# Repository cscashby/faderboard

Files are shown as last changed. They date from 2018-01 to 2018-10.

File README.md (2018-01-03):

# Fader Board (AKA Fraken-Mixer)

Multi-channel DAW control designed for portable wireless musical theatre use

## Problem statement

Normally musical theatre shows involve a fairly high number of radio microphones and a decent sized band/orchestra.  Generally in order to avoid feedback and other issues, the sound engineer needs to closely monitor / mix and quickly change faders during each scene to minimise the number of mics 'live' at any one time, and adjust for differences in the actors' voices and song dynamics.

In a traditional proscenium theatre this is fairly easy - a space is reserved at the back for the mix position, and the mixer and processing equipment (as well as the source for any SFX) is at the rear of the hall.

Enter promenade, or immersive, musical theatre - where the cast and audience are often in the same space, and the audience move through a number of rooms as the cast and the action takes them.

This is a very new genre of musical theatre, and hasn't really been done on a professional scale before - at least to my knowledge - and so when I was asked to do [Parade in Hemel Hempstead's Frogmore Paper Mill by Vivo D'Arte](http://www.vivodarte.co.uk/news.htm) - which required 20 radio microphones, a 7 piece orchestra, all in 5 different spaces, I apprehensively grasped at the challenge.

My approach at the time was to use a [Behringer Xtouch](https://www.musictri.be/Categories/Behringer/Computer-Audio/Desktop-Controllers/X-TOUCH/p/P0B1X) control surface, with a battery power unit and WiFi access client.  The result was good<sup>[1](#myfootnote1)</sup>, but it was a challenge because I only had 8 faders to use, couldn't change the 'page' or 'scene' myself, and couldn't trigger SFX or change speaker routing; I had a very capable team working with me who could do all of the above, so I managed, but it also was a very heavy box of tricks.

Another issue which arose over time was that the WiFi control was patchy - as the Xtouch isn't designed to be used with a spotty network connection, and being WiFi across a large space, the access client needed to disconnect and reconnect between multiple access points, disconnections were difficult - the Xtouch actually drops all the faders to -∞ so if you happen to touch them as it reconnects the channel dies unexpectedly. Not great.

So, what is required is a custom-built control surface which can control a number of channels of a mixing desk, without the constraints of a direct control solution like the Xtouch, and without the inherent problems with WiFi.

## Initial thoughts / concepts

### Scribble

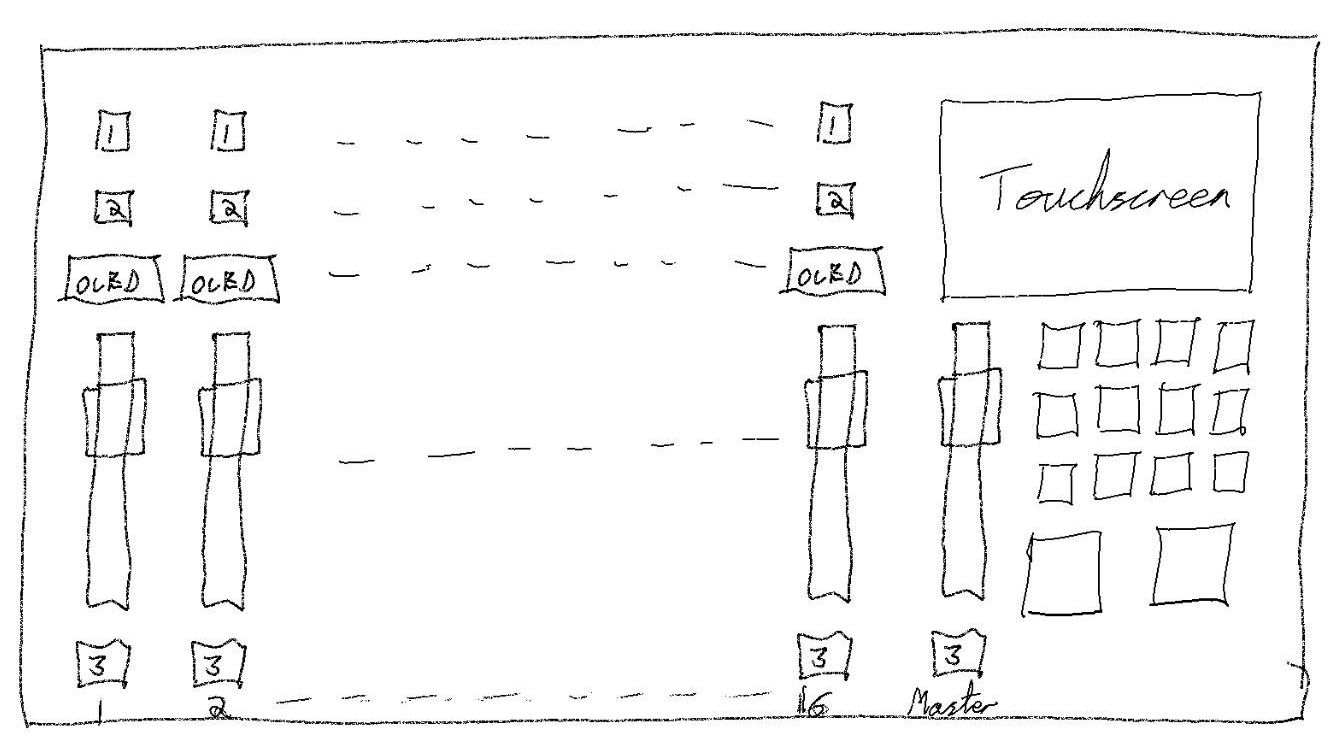
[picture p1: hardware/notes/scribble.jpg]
Scribbled picture of faderboard


Not very tidy, but hopefully this helps illustrate what's supposed to be happening.

### Tech decision

I went for an Arduino base for this project as I need embedded reliability and performance, without the overheads and inherent risks of using a SoC like the Raspberry Pi.  Given the complexity and number of I/O connections needed, I am basing the solution on an AT Mega 2560 - I got hold of [this dev board](http://amzn.to/2lO5UGc), but will probably design my own board from scratch for compactness

### Wireless comms

I need a long-range, full duplex transmit/receive solution for reasonably small payloads with a limited amount of overhead / latency.  I came across [LoRa](https://www.lora-alliance.org/) which seems to fit the bill, and I bought a couple of [dev boards for the RA-02 chip](http://amzn.to/2ELpx9M) which uses 433 MHz (or a couple of other free to use frequenceis).  I haven't completed testing yet but it seems to work well for my purposes.  What's more as it's designed for IoT, multiple receivers can be used to widen the transmit range if needed.

### Faders

Key to the solution is going to be the quality of fader units available, and they have to be motorised so they can be preset to values, and so that the sound #2s can also control if required.

Rather than evaluate a whole bunch of faders, I decided to buy [replacement faders for the Xtouch unit](https://www.gear4music.com/PA-DJ-and-Lighting/Behringer-X-Touch-Motor-Fader-MF100T-Set-of-5/1WME) instead - they are not that expensive, and I know them to be good.  They are 10 kΩ linear slide pots with a fast, accurate motor, and a touch sensitivity (capacitive touch) pin.

Touch sensitivity isn't something I've previously thought about, but this is a great option as it means that I can minimise my payload sent over the wire to only those faders which are being touched - making the device hopefully far more responsive.

### Scribble strips

Every good sound engineer deserves scribble strips (or something!) - they are invaluable for Musical Theatre - as each scene has different DCA assignments running, you can very quickly forget where you are as an operator.

I wanted multiple colours - as colour is a great way to distinguish between each channel.

I came across [these little OLED displays](https://thepihut.com/products/adafruit-monochrome-0-96-128x64-oled-graphic-display) which seem perfect as they're small, bright and easy to control via SPI.  I haven't yet received them so I'll update here as to how suitable they are.

Controlling lots of them isn't directly supported by their libraries so I'll need to do some custom coding to modify them for multiple units - multiplexing them through multiple CS pins.

### Everything else

I decided to duplicate the work I did in another project - '[pi-showcontrol'](github.com/cscashby/pi-showcontrol) and have a small TFT screen and programmable buttons in a 'master section' in the box - that way I can use SFX and have some feedback, possibly even plain text sent back to me by the Sound #2s which will hopefully be very useful.

### Power supply

This is probably the thing I've thought the least about.  I have a very reliable, high power battery which will give me any DC voltage I like and sensibly monitor time remaining, so I may stick with that for now; so a 5.5mm/2.5mm DC power jack may be all I need - probably 12v to minimise voltage regulator heating and run the whole thing at 5v.  However, if I feel brave later on I may well implement a battery control / charge unit.

### Physical manufacture

In my mind at present, I think the best approach is going to be to create a number of different PCBs:

1. Faders - in groups of 8 (so two identical boards).
2. Master control section - the TFT (although this may just be a module bolted to the case), buttons and big 'go' buttons).
3. Control board - the Arduino, radio chips and logic required to get the thing running.
4. Power supply - not sure what this will entail yet - watch this space.

I'd like to keep the unit as light as possible, but it will need sensible shielding (likely with pass-through capacitors for the 433 MHz antennae) - so I will be building the case out of sheet aluminium, probably cut using a CNC mill, or laser cut by a third party fabrication shop.  All of the controls will be mounted on the top panel, the control / power boards likely on the bottom panel, and the rear will be used for wired connections for charging, firmware upgrades and diagnostics.

On the sides of the box (which will likely need to be thicker / better reinforced) I will have holes for the straps which I will wear to use the unit whilst walking around (in [ice cream tray style](http://www.promotional-images.co.uk/ProdImages/2f9f440d-2c25-4093-97b0-d831b5edaa2b/classic2-lg.jpg) without the ice creams)

### The other end

Again this is early stages of the thought process, but a LoRa chip (probably the development board itself) with an ethernet HAT, which delivers an OSC payload to the mixing desk or a mac running [qLab](http://www.figure53.com/qlab).  Some form of queuing will be required so that if I end up with more than one of the receivers, then a controller will be required to marshal, deduplicate and send on this queue.

## Footnotes

<a name="myfootnote1">1</a>: 'No sitting at the back for him – [cscashby] he too followed the audience around with his sound desk in an usherette’s tray, ensuring that every cast member was heard, no matter what part of the building they were in.' [from Musical Theatre Review](http://musicaltheatrereview.com/parade-frogmore-paper-mill-hemel-hempstead/)

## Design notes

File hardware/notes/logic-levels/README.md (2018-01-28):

# Logic level conversion

Unfortunately the MPR121 is a 3.3v device not a 5v device, so I have decided to replace this more functional device with two CAP1296 devices, which only support 6 channels but don't require complex level shifting technology.

In case I need the MPR121 - I have included a reference to the Adafruit level shifter library which appears to be a good I2C solution.

https://github.com/adafruit/4-Channel-Level-Shifter-PCB

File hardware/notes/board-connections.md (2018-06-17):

# Faderboard connector layout

## CURRENT v1.0 board

|  **Connector** | **Pin** | **Signal Name** | **Notes** |
|  ---: | :---: | :---: | --- |
|  FD-J1 | 1 | GND |  |
|  FD-J1 | 2 | VCC / VDD | +3.3v |
|  FD-J1 | 3 | VREF | Vref |
|  FD-J1 | 4 | VMOTOR | +9v |
|  FD-J1 | 5 | GND | |
|  FD-J1 | 6 | VMOTOR | +9v |
|  FD-J1 | 7 | FSDAa | Fader touch I2C (1-4) |
|  FD-J1 | 8 | MCTLA | Motor Control |
|  FD-J1 | 9 | FSCLa | Fader touch I2C (1-4) |
|  FD-J1 | 10 | MCTLB | Motor Control |
|  FD-J1 | 11 | FI̅N̅T̅a | Fader touch interrupt (1-4) |
|  FD-J1 | 12 | BSEL | Board select (active HIGH) |
|  FD-J1 | 13 | FSDAb | Fader touch I2C (5-8) |
|  FD-J1 | 14 | FADER | Fader GND->Vref analogue |
|  FD-J1 | 15 | FSCLb | Fader touch I2C (5-8) |
|  FD-J1 | 16 | MA0 | Motor address LSB |
|  FD-J1 | 17 | FI̅N̅T̅b | Fader touch interrupt (5-8) |
|  FD-J1 | 18 | MA1 | Motor address |
|  FD-J1 | 19 | MA2 | Motor address MSB |
|  FD-J1 | 20 | FA0 | Fader address LSB |
|  FD-J1 | 21 | FA1 | Fader address |
|  FD-J1 | 22 | FA2 | Fader address MSB |
|  FD-J1 | 23 | GND | |
|  FD-J1 | 24 | DA0 | Display address LSB |
|  FD-J1 | 25 | DA1 | Display address |
|  FD-J1 | 26 | DA2 | Display address MSB |
|  FD-J1 | 27 | GND | |
|  FD-J1 | 28 | DSDA | Display SDA |
|  FD-J1 | 29 | DDC̅ | Display D/C |
|  FD-J1 | 30 | DSCL | Display SCL |
|  FD-J1 | 31 | DC̅S̅ | Display CS |
|  FD-J1 | 32 | DR̅S̅T̅ | Display Reset |

#### Connector layout

|  **Name** | **Pin** | **Pin** | **Name** |
|  ---: | :---: | :---: | --- |
|  GND | 1 | 2 | VCC / VDD |
|  VREF | 3 | 4 | VMOTOR |
|  GND | 5 | 6 | VMOTOR |
|  FSDAa | 7 | 8 | MCTLA |
|  FSCLa | 9 | 10 | MCTLB |
|  FI̅N̅T̅a | 11 | 12 | BSEL |
|  FSDAb | 13 | 14 | FADER |
|  FSCLb | 15 | 16 | MA0 |
|  FI̅N̅T̅b | 17 | 18 | MA1 |
|  MA2 | 19 | 20 | FA0 |
|  FA1 | 21 | 22 | FA2 |
|  GND | 23 | 24 | DA0 |
|  DA1 | 25 | 26 | DA2 |
|  GND | 27 | 28 | DSDA |
|  DDC̅ | 29 | 30 | DSCL |
|  DC̅S̅ | 31 | 32 | DR̅S̅T̅ |

## OLD VERSION v0.1

### 8-fader and OLED board

#### By pin

|  **Connector** | **Pin** | **Signal Name** | **Notes** |
|  ---: | :---: | :---: | --- |
|  FD-J1 | 1 | GND |  |
|  FD-J1 | 2 | VCC / VDD | +3.3v |
|  FD-J1 | 3 | VREF | Vref |
|  FD-J1 | 4 | GND |  |
|  FD-J1 | 5 | GND |  |
|  FD-J1 | 6 | VMOTOR | +12v TBC |
|  FD-J1 | 7 | FSDAa | I2C for first CAP1296 |
|  FD-J1 | 8 | MCTLA | Motor Control |
|  FD-J1 | 9 | FSCLa | I2C for first CAP1296 |
|  FD-J1 | 10 | MCTLB | Motor Control |
|  FD-J1 | 11 | GND |  |
|  FD-J1 | 12 | FIRQ | For touch (active Low) |
|  FD-J1 | 13 | FSDAb | I2C for first CAP1296 |
|  FD-J1 | 14 | FADER | Fader GND->Vref |
|  FD-J1 | 15 | FSCLb | I2C for first CAP1296 |
|  FD-J1 | 16 | MA0 | Motor address LSB |
|  FD-J1 | 17 | MA1 | Motor address |
|  FD-J1 | 18 | MA2 | Motor address MSB |
|  FD-J1 | 19 | MA3 | Motor enable for board (active High) |
|  FD-J1 | 20 | FA0 | Fader address LSB |
|  FD-J1 | 21 | FA1 | Fader address |
|  FD-J1 | 22 | FA2 | Fader address MSB |
|  FD-J1 | 23 | FA3 | Fader enable for board (active High) |
|  FD-J1 | 24 | DA0 | Display address LSB |
|  FD-J1 | 25 | DA1 | Display address |
|  FD-J1 | 26 | DA2 | Display address MSB |
|  FD-J1 | 27 | DA3 | Display enable for board (active High) |
|  FD-J1 | 28 | DRST | Display Reset |
|  FD-J1 | 29 | DDC | Display D/C |
|  FD-J1 | 30 | BSEL | Board select (MPR121 I2C addr GND = 0x5a, VCC = 0x5b) |
|  FD-J1 | 31 | GND |  |
|  FD-J1 | 32 | GND |  |

#### Connector layout

|  **Name** | **Pin** | **Pin** | **Name** |
|  ---: | :---: | :---: | --- |
|  GND | 1 | 2 | VCC / VDD |
|  VREF | 3 | 4 | GND |
|  GND | 5 | 6 | VMOTOR |
|  FSDAa | 7 | 8 | MCTLA |
|  FSCLa | 9 | 10 | MCTLB |
|  GND | 11 | 12 | FIRQ |
|  FSDAb | 13 | 14 | FADER |
|  FSCLb | 15 | 16 | MA0 |
|  MA1 | 17 | 18 | MA2 |
|  MA3 | 19 | 20 | FA0 |
|  FA1 | 21 | 22 | FA2 |
|  FA3 | 23 | 24 | DA0 |
|  DA1 | 25 | 26 | DA2 |
|  DA3 | 27 | 28 | DRST |
|  DDC | 29 | 30 | BSEL |
|  GND | 31 | 32 | GND |

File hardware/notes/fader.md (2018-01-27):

Fader appears to be an Alps RSA0N11M9A0J.

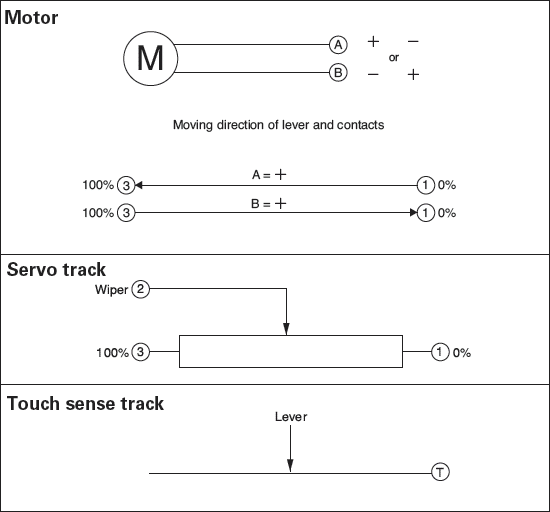
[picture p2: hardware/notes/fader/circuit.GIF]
Fader Circuit Fader circuit


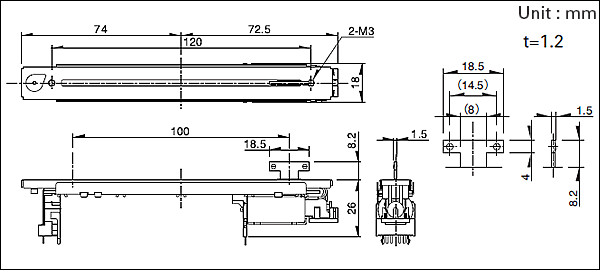
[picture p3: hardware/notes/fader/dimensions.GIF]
Fader Dimensions Fader dimensions


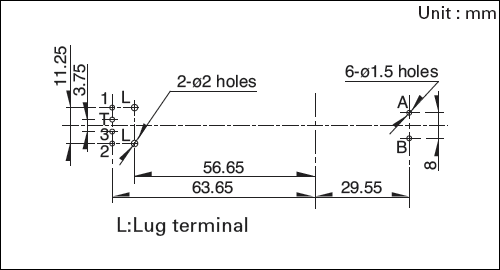
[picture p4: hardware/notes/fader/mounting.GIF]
Fader Mounting Fader mounting


Specs:

Number of resistor elements | Single-unit |
Direction of lever | Vertical |
Travel | 100mm |
Type | Motor N fader |
Lever type | 9-T (T-Bar) |
Length of lever | 8.2mm |
Total resistance | 10kΩ |
Resistance taper | 1B |
Terminal style | For PC board |
Touch sense track | With |
Operating temperature range | -10°C to +60°C |
Electrical performance | Total resistance tolerance | ±20%
Maximum operating voltage | 500V AC, 10V DC |
Rated voltage of motor | 10V DC |
Maximum current of motor | 800mA or less (at 10V DC) |
Rated power | 0.5W |
Insulation resistance | 100MΩ min. 250V DC |
Voltage proof | 250V AC for 1 minute |
Mechanical performance | Operating force | 0.8±0.5N |
Stopper strength | 100N |
Lever push-pull strength | 50N |
Lever wobble (Both side) | 1.312mm |
Lever deviation (One side) | 0.5mm max. |
Durability | Operating life | 30,000 cycles |
Minimum order unit (pcs.) | Japan | 80
Export | 160 |

http://www.alps.com/prod/info/E/HTML/Potentiometer/SlidePotentiometers/RSN1M/RSA0N11M9A0J.html

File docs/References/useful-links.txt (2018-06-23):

Mega2560 docs:

https://store.arduino.cc/arduino-mega-2560-rev3

Multiplexing SPI lines:

https://forum.arduino.cc/index.php?topic=461410.0

Arduino/LoRA:

https://github.com/sandeepmistry/arduino-LoRa#semtech-sx1276777879-wiring

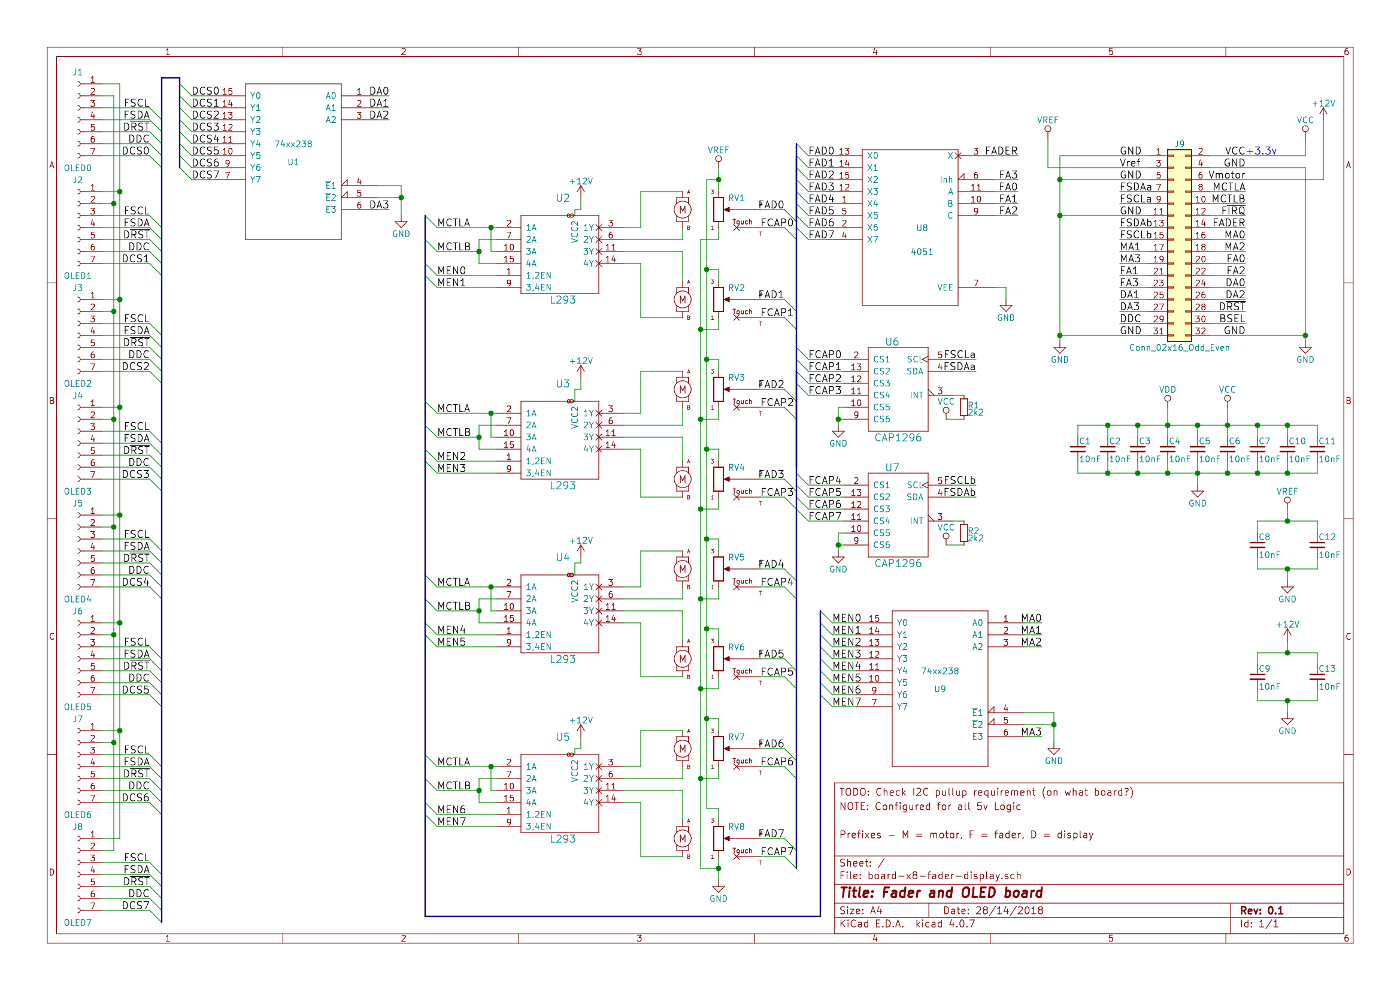
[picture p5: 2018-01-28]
hardware/board-x8-fader-display.v0.1.png

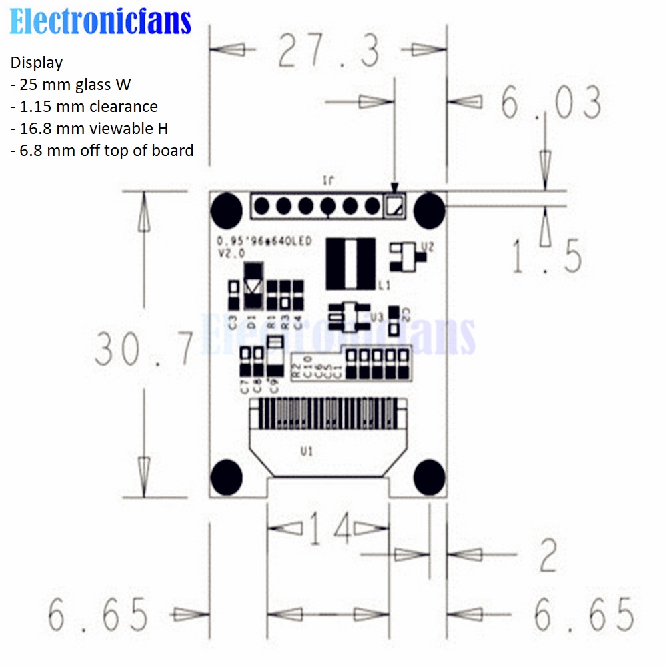
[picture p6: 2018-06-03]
docs/Datasheets/0-95-Inch-SPI-Full-Color-OLED-Display-DIY-Module-96x64-LCD-For-Arduino-SSD1306-Driver.jpg

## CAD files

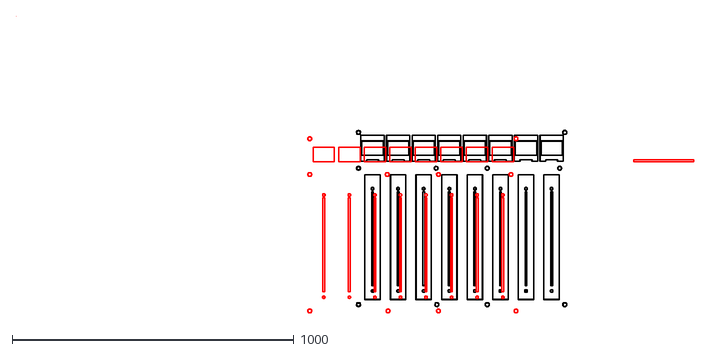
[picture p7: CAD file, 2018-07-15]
docs/Boards/Fader T-Slot Box.dxf
2401.2 x 1052.8

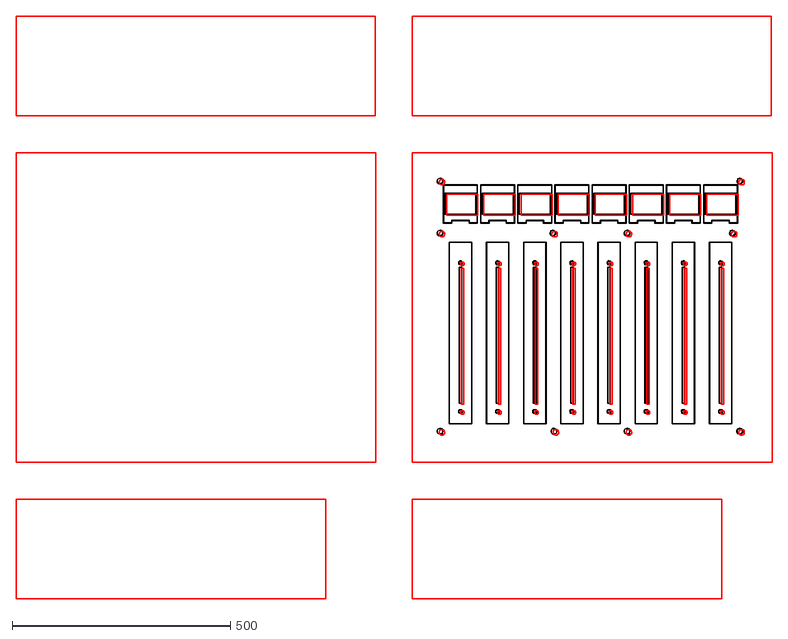
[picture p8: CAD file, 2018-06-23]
docs/Boards/Fader Lasercut.dxf
1730.4 x 1332.3

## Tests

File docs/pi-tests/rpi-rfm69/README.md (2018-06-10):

Pi setup notes

raspi-config #- enable SPI
pip install rpi-rfm69

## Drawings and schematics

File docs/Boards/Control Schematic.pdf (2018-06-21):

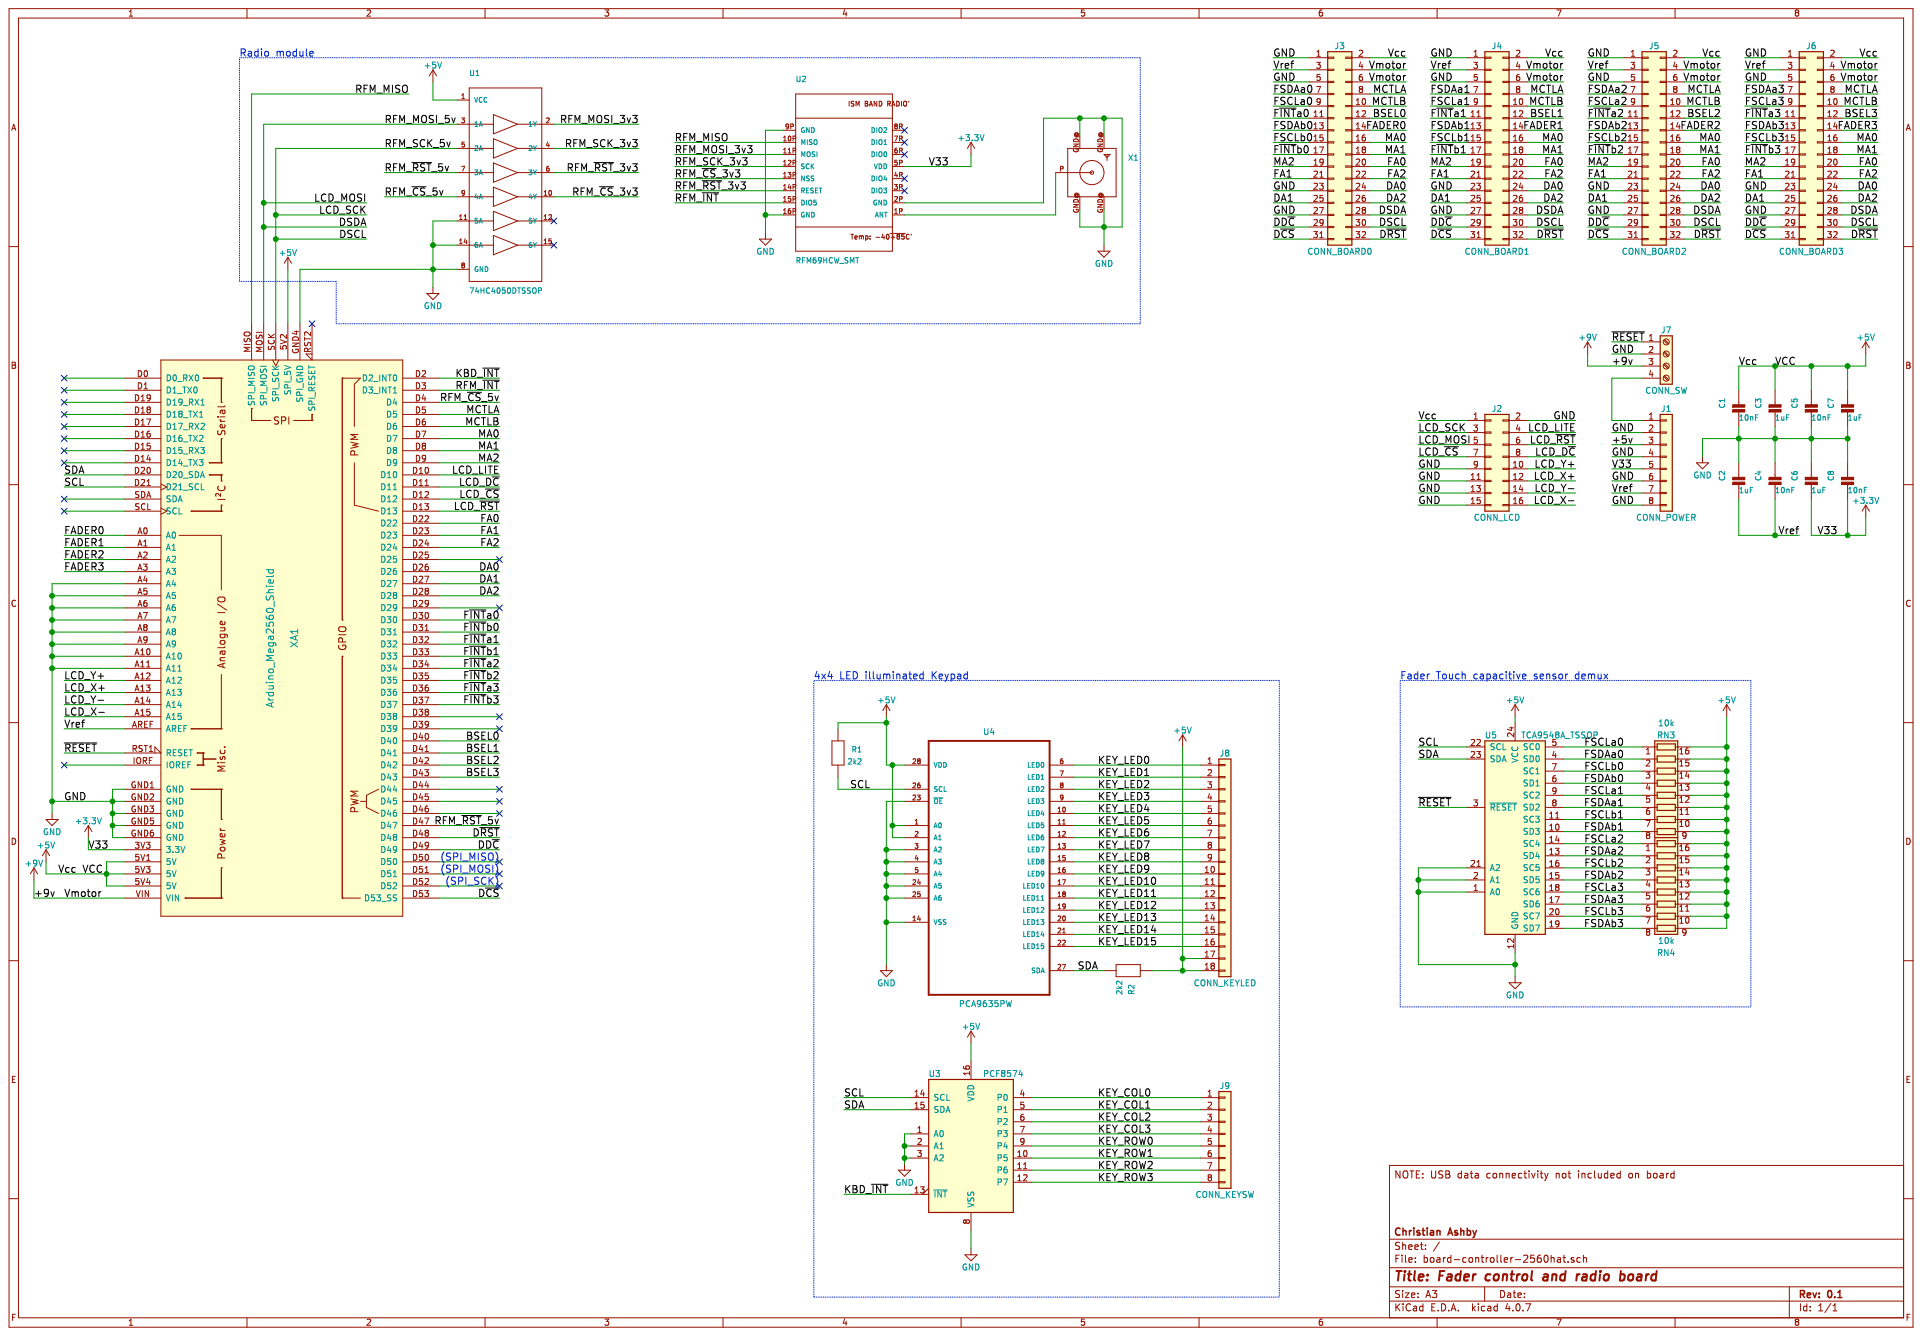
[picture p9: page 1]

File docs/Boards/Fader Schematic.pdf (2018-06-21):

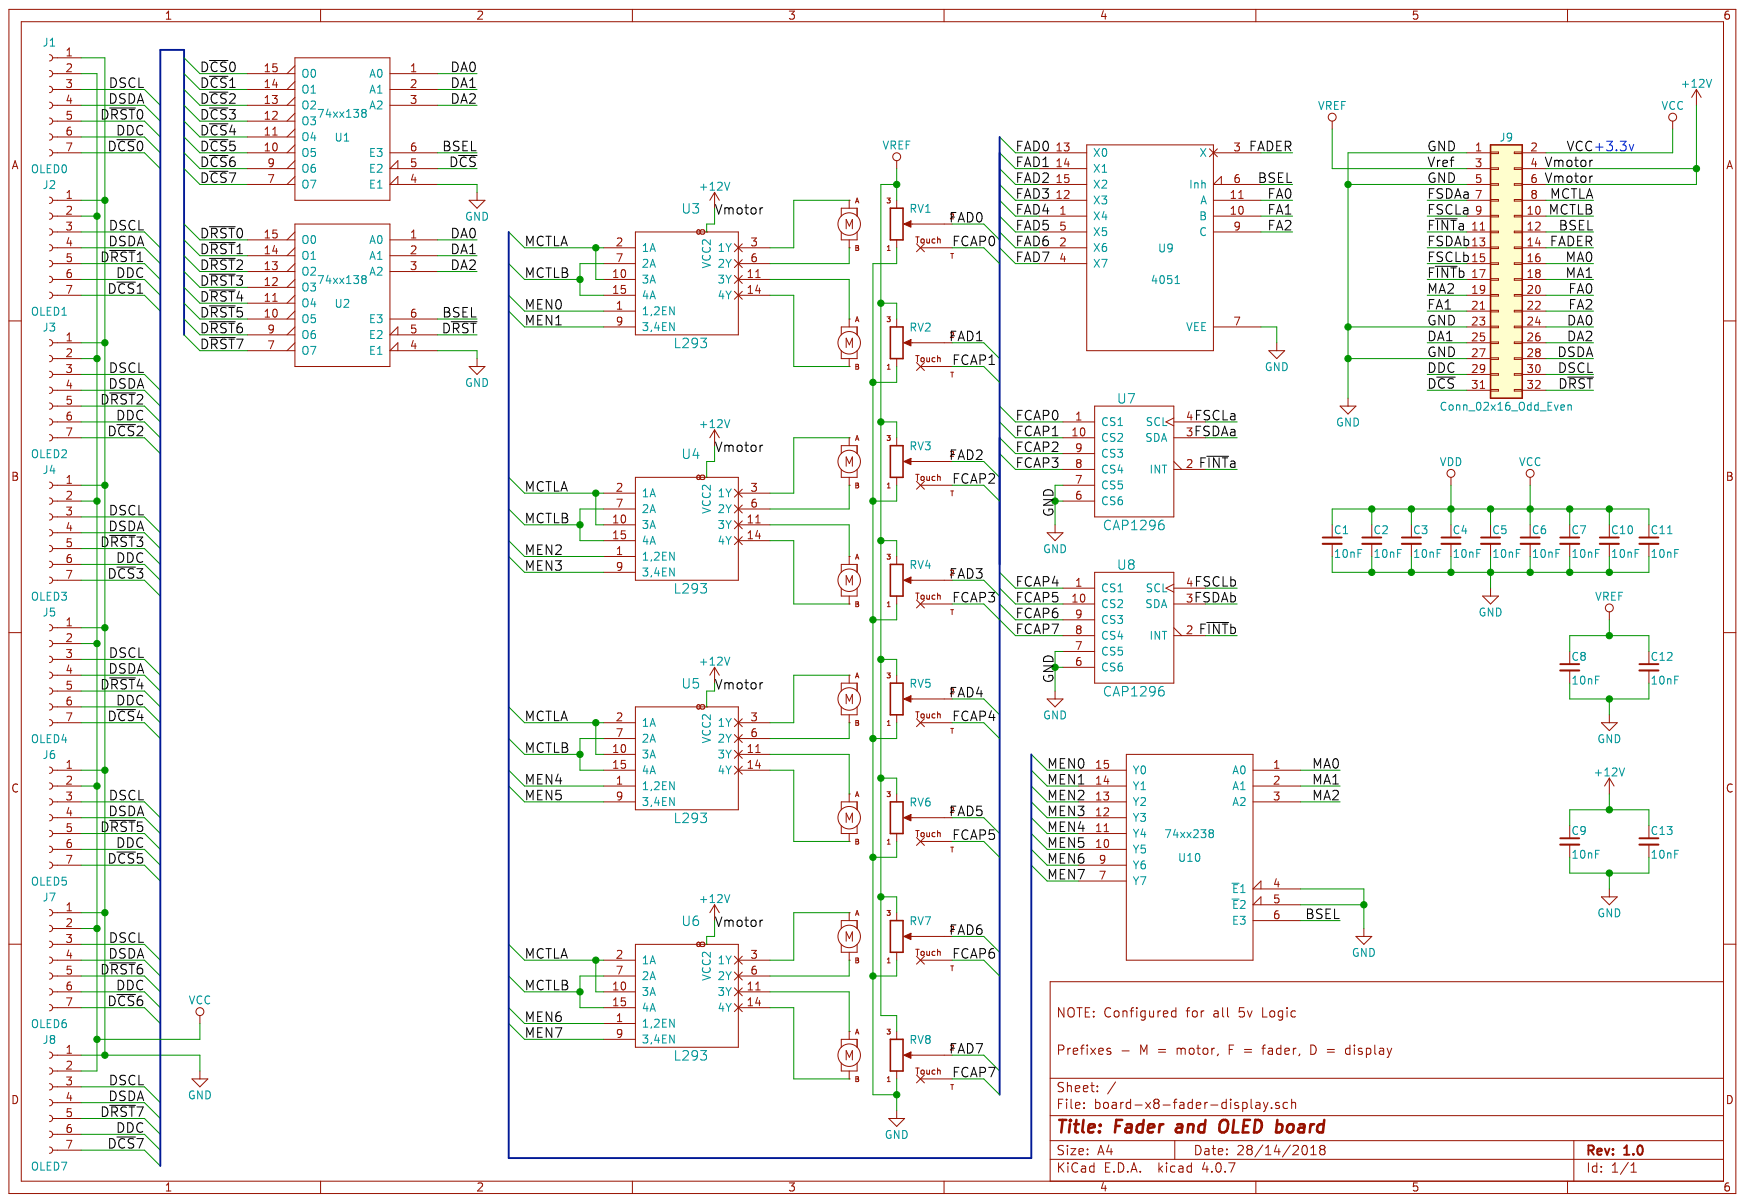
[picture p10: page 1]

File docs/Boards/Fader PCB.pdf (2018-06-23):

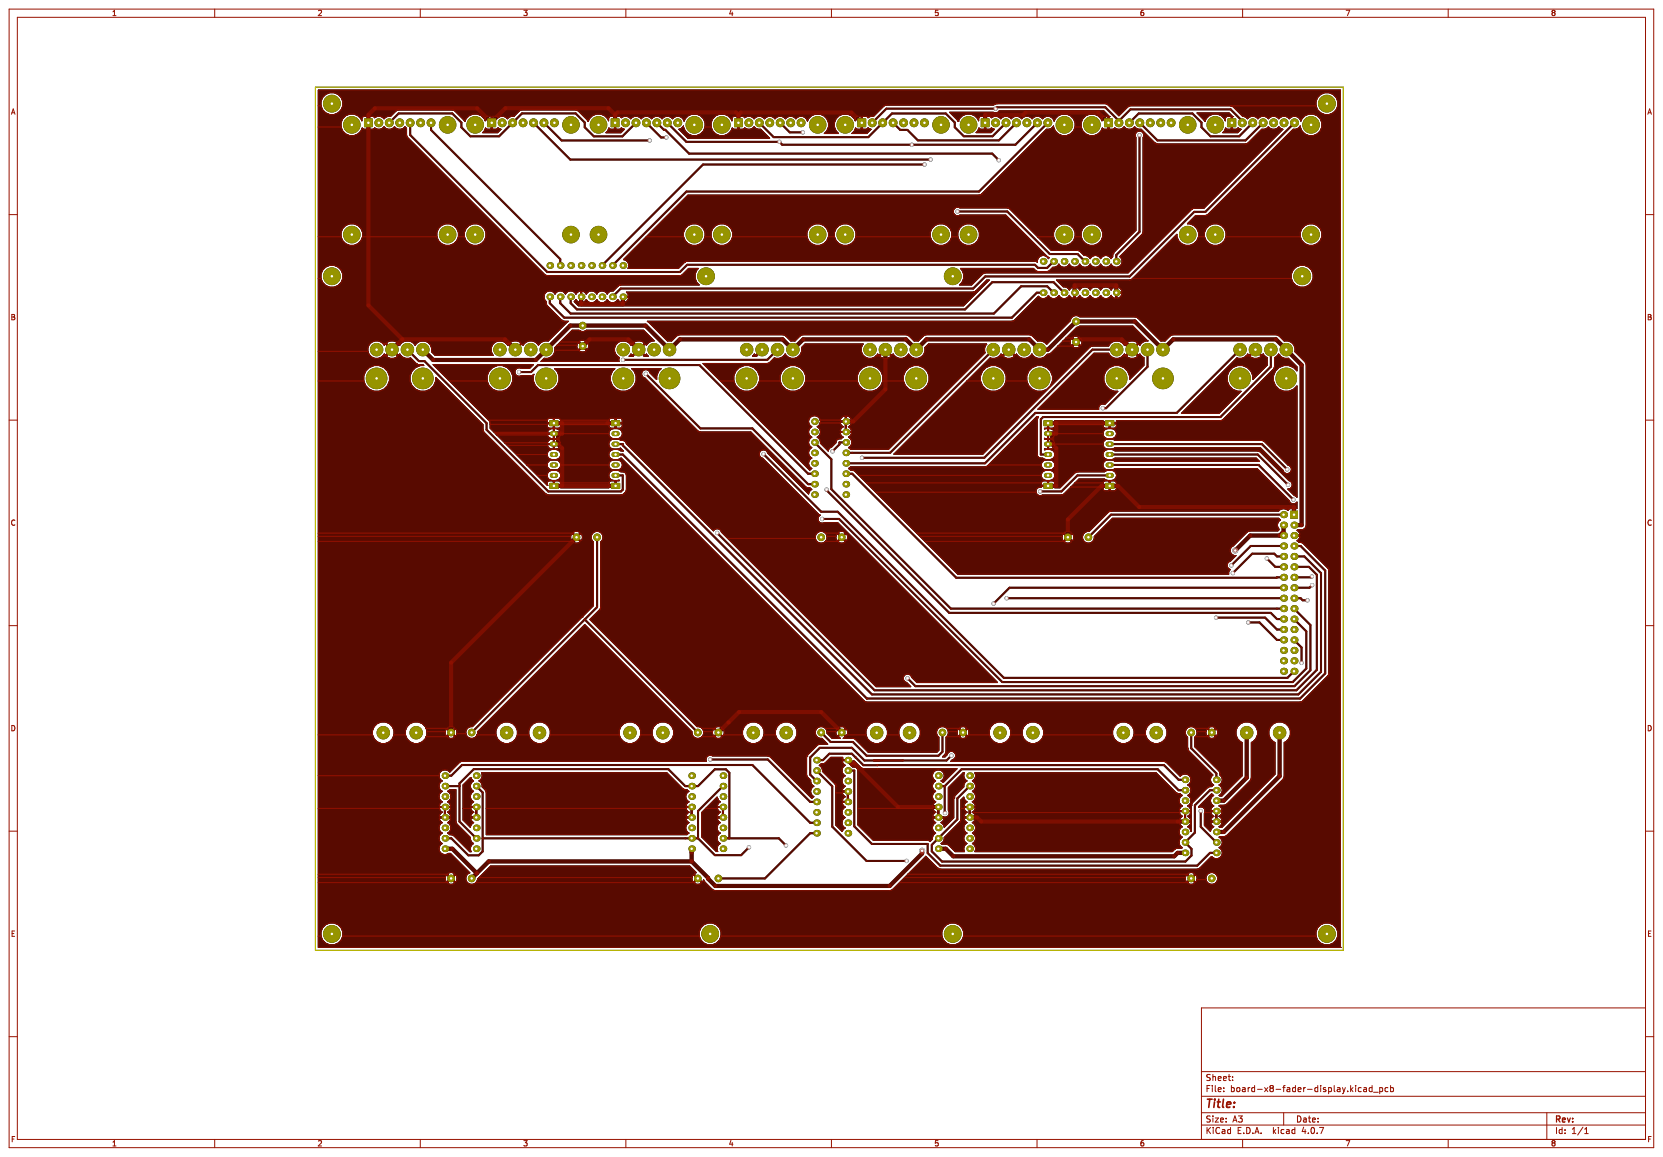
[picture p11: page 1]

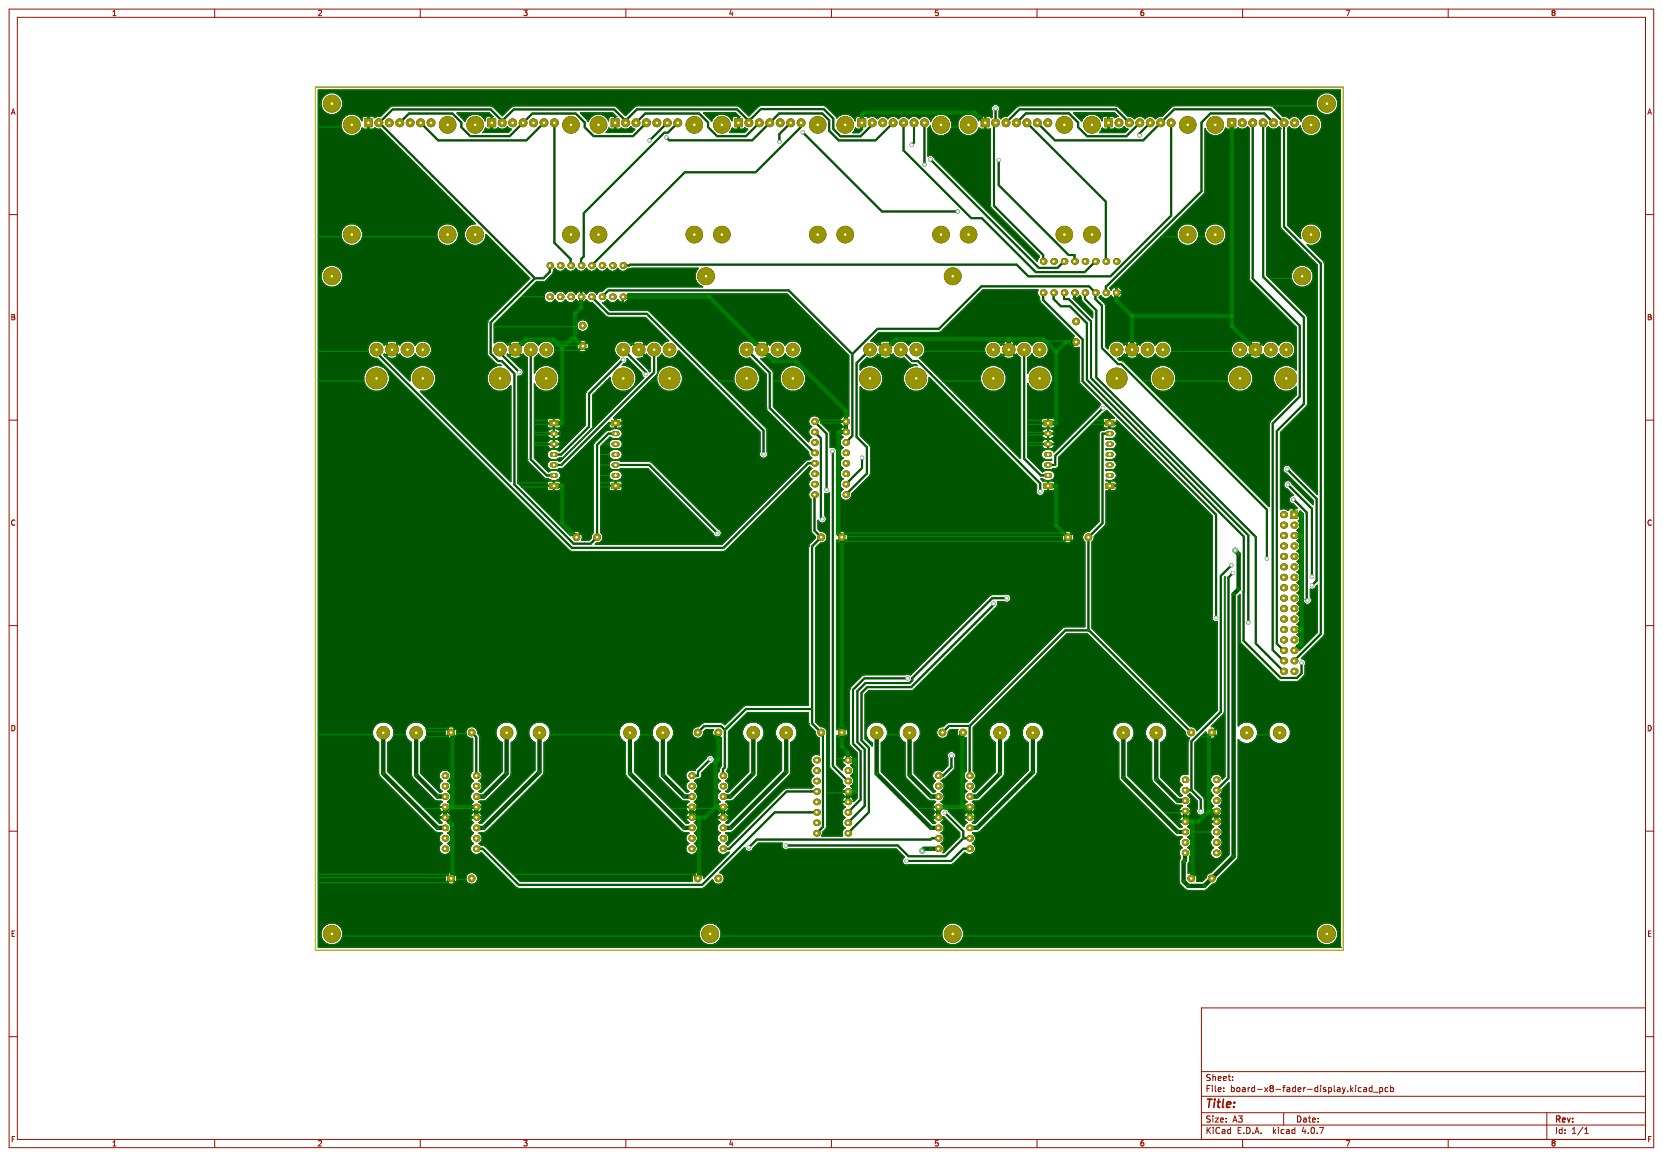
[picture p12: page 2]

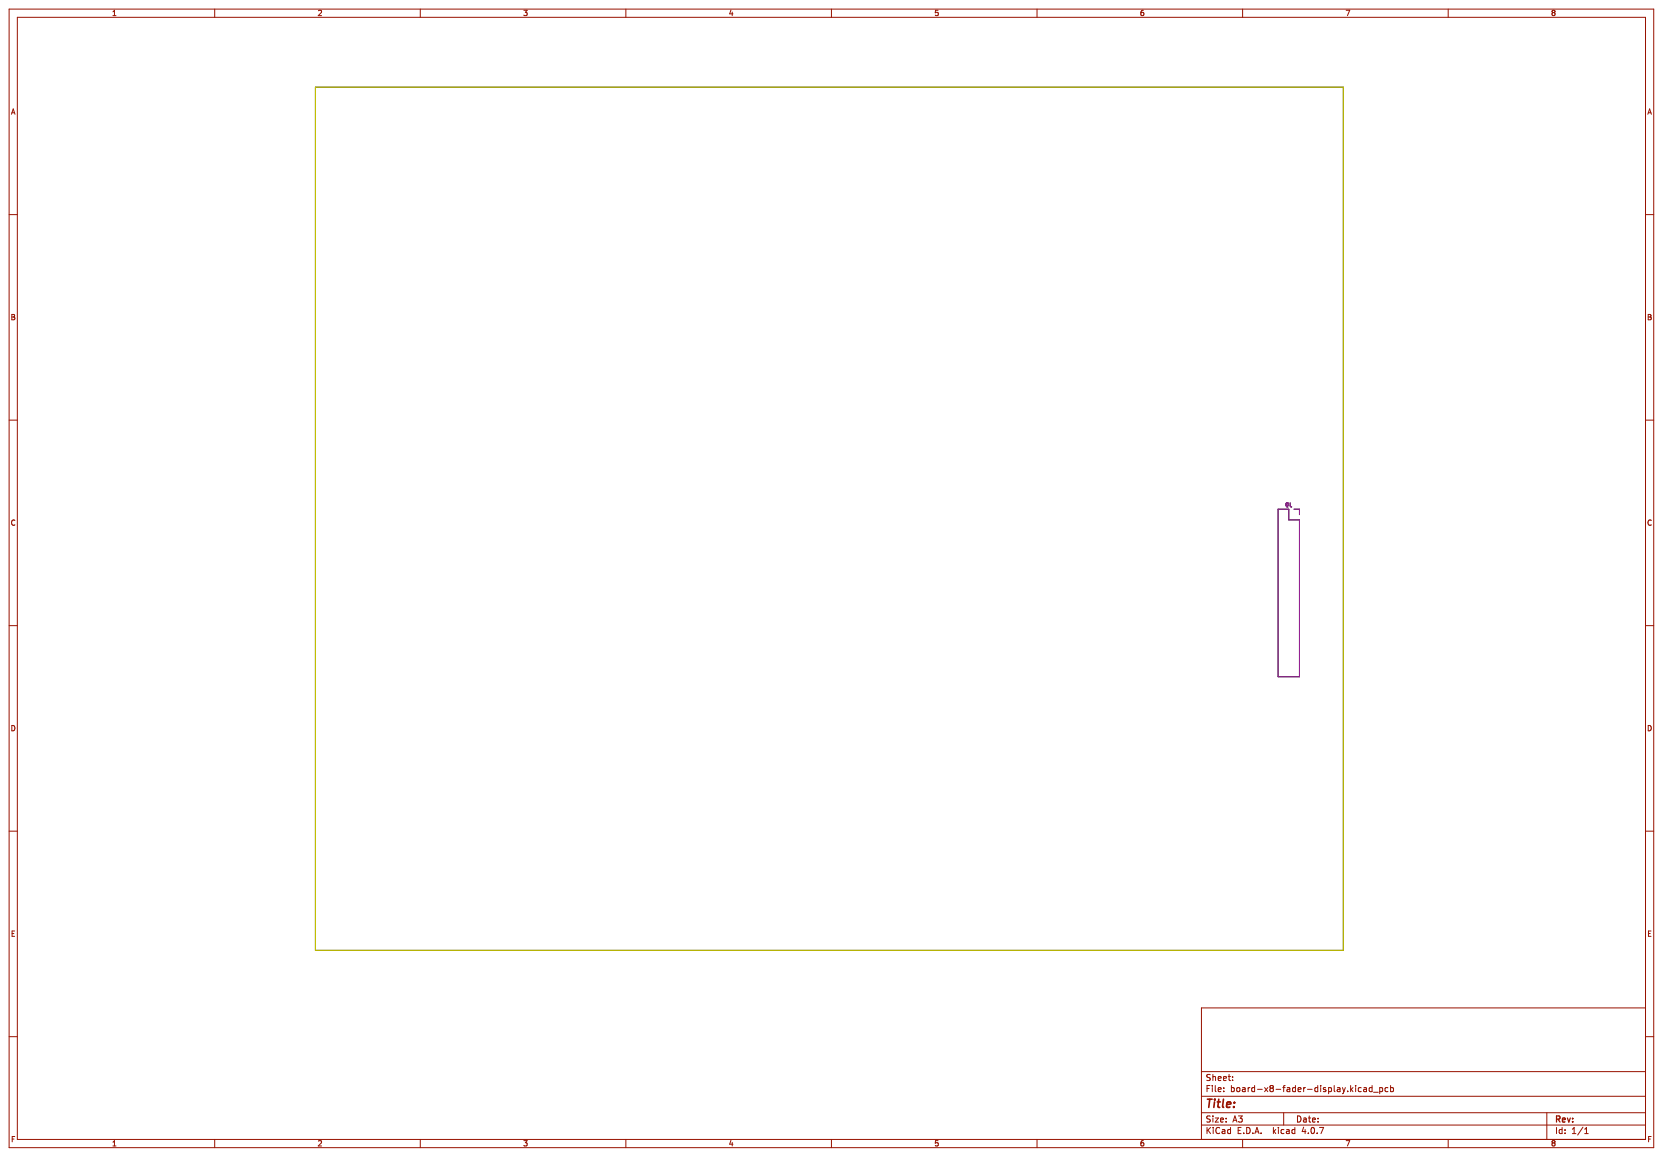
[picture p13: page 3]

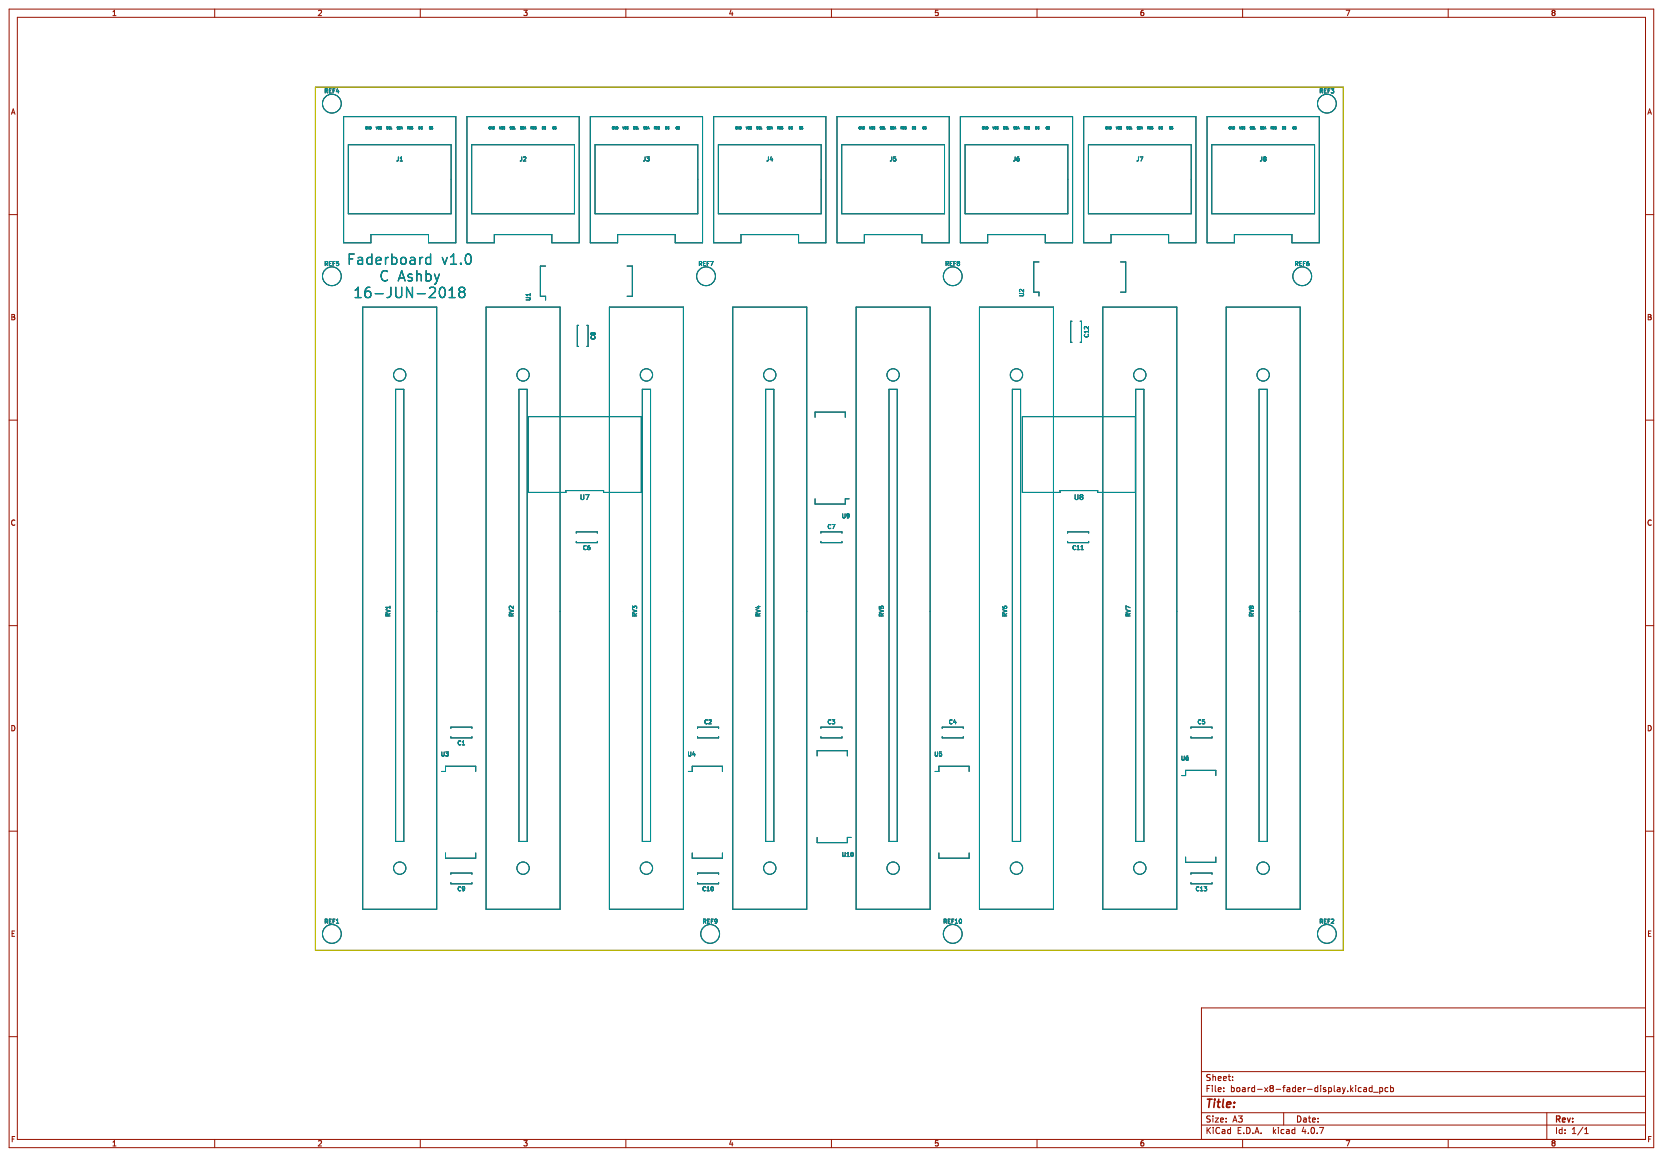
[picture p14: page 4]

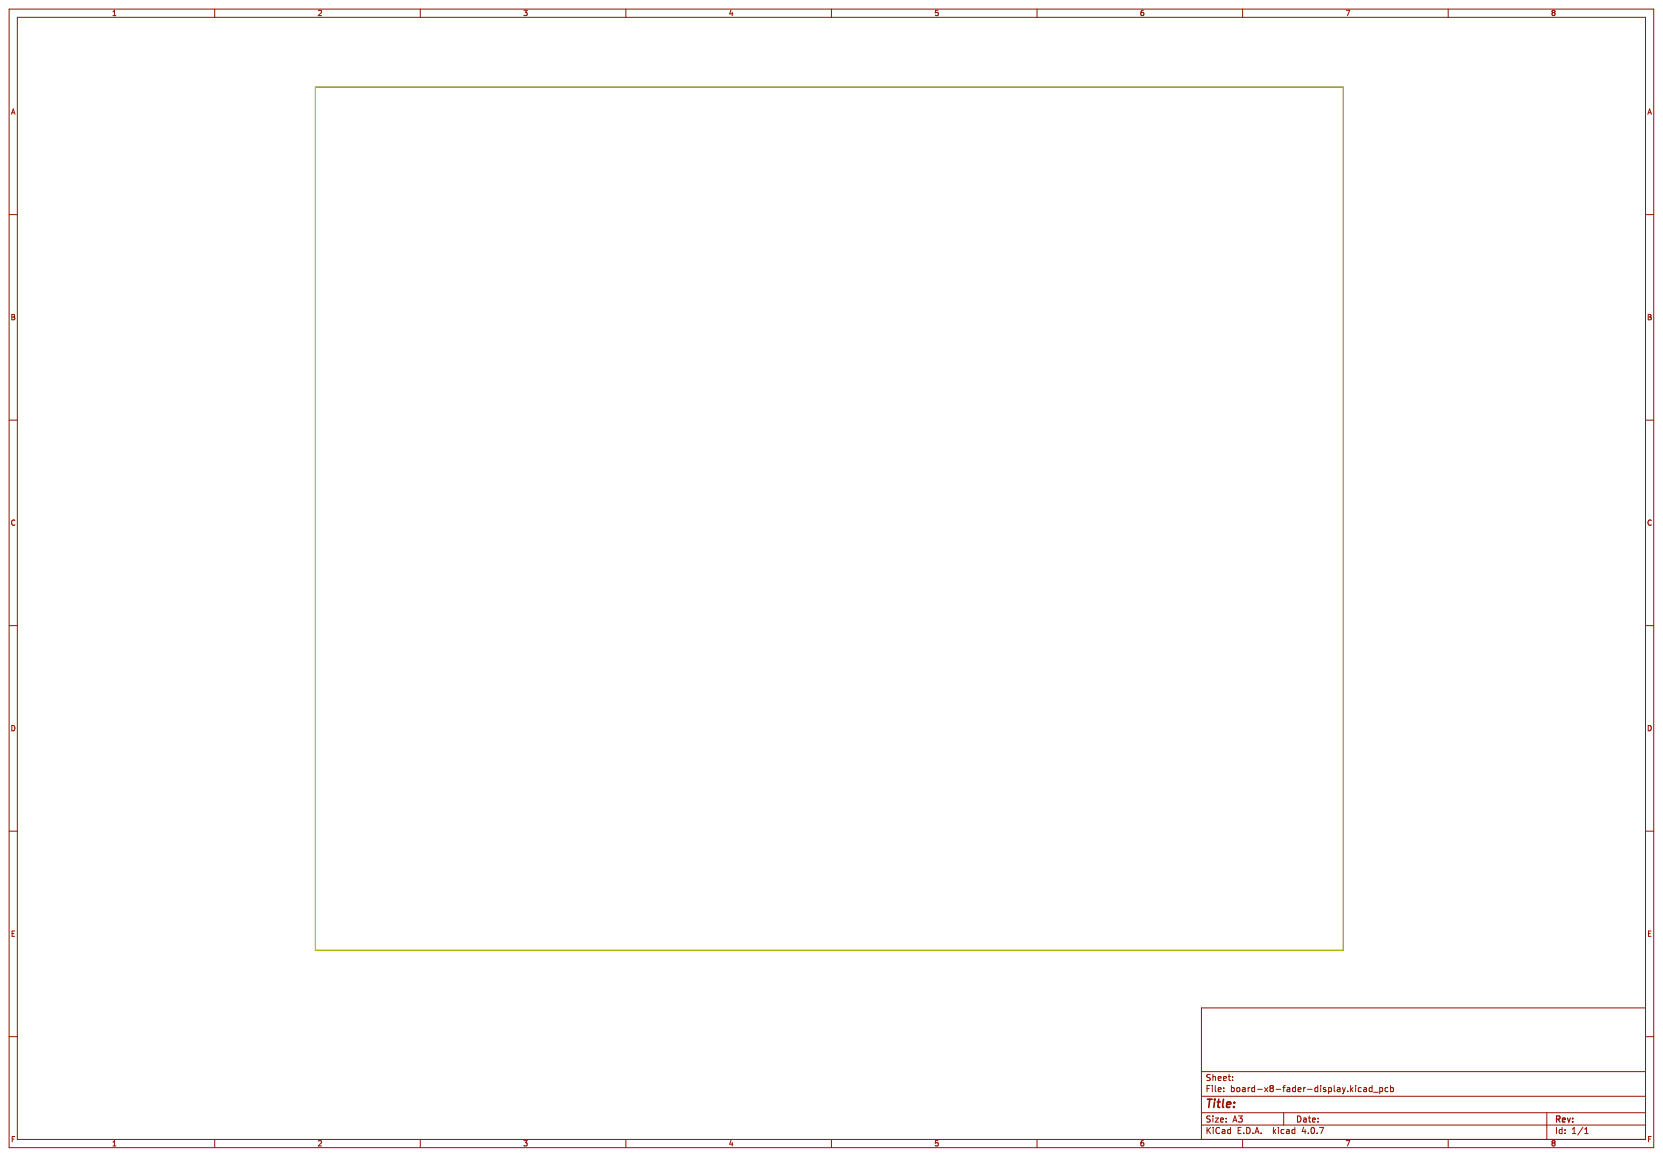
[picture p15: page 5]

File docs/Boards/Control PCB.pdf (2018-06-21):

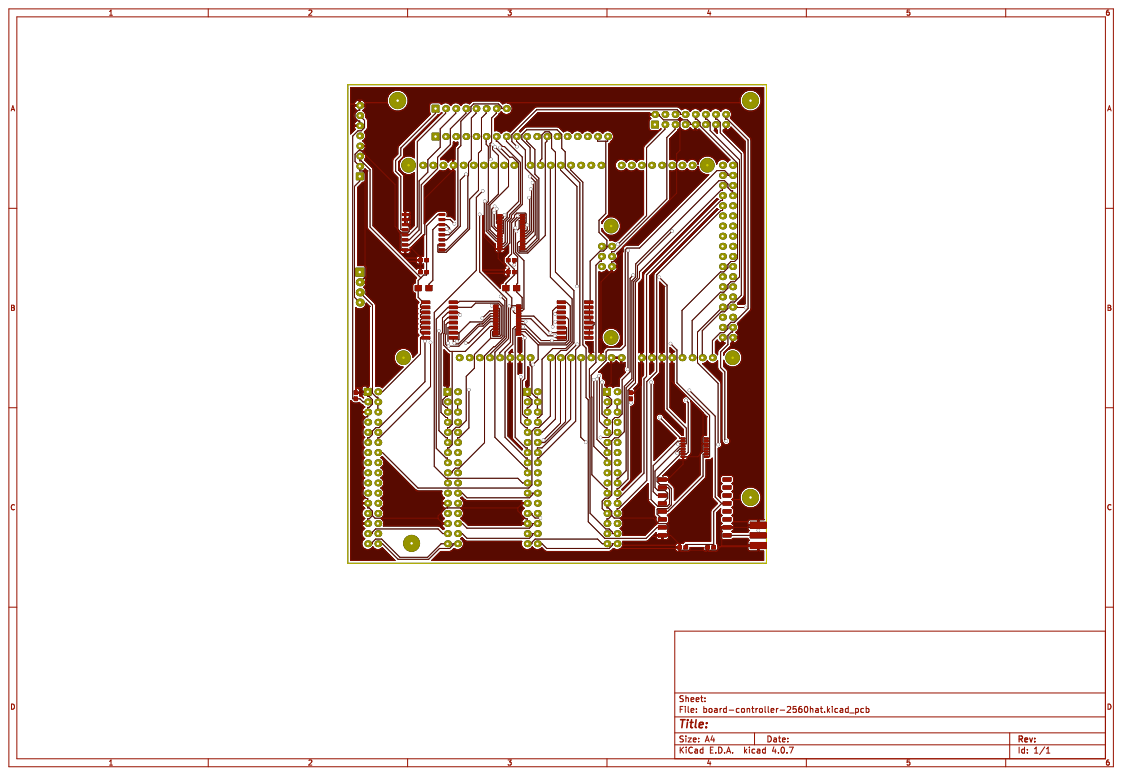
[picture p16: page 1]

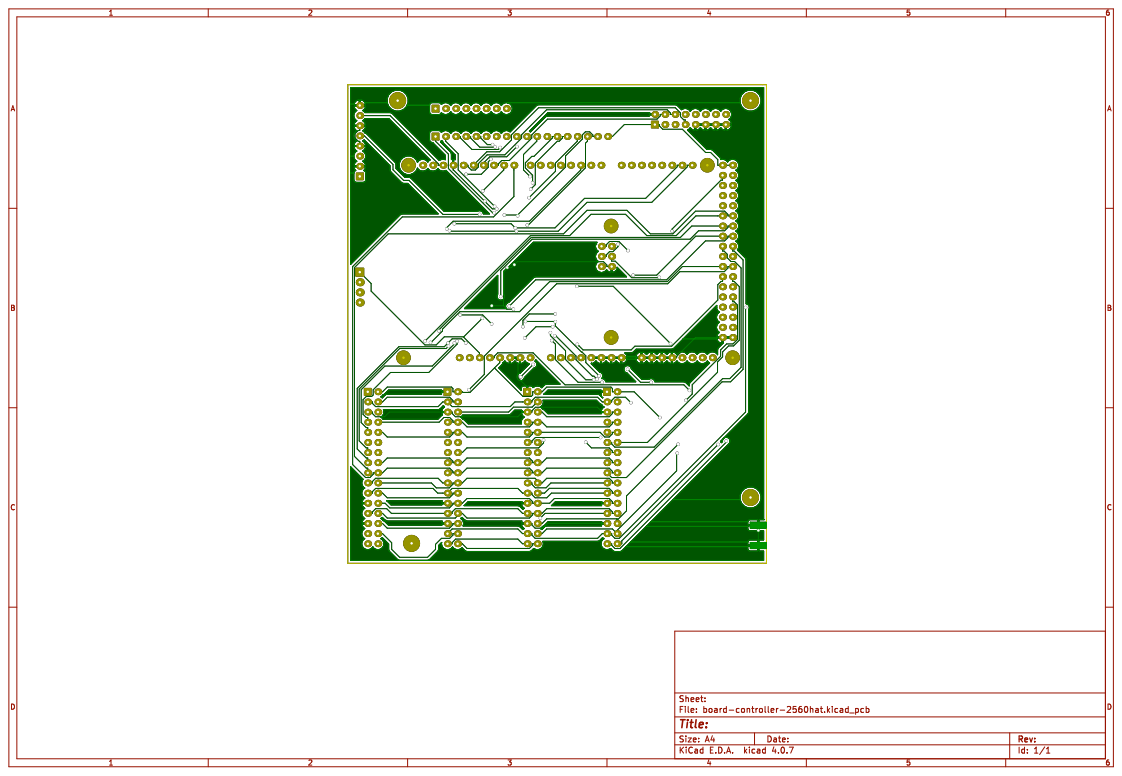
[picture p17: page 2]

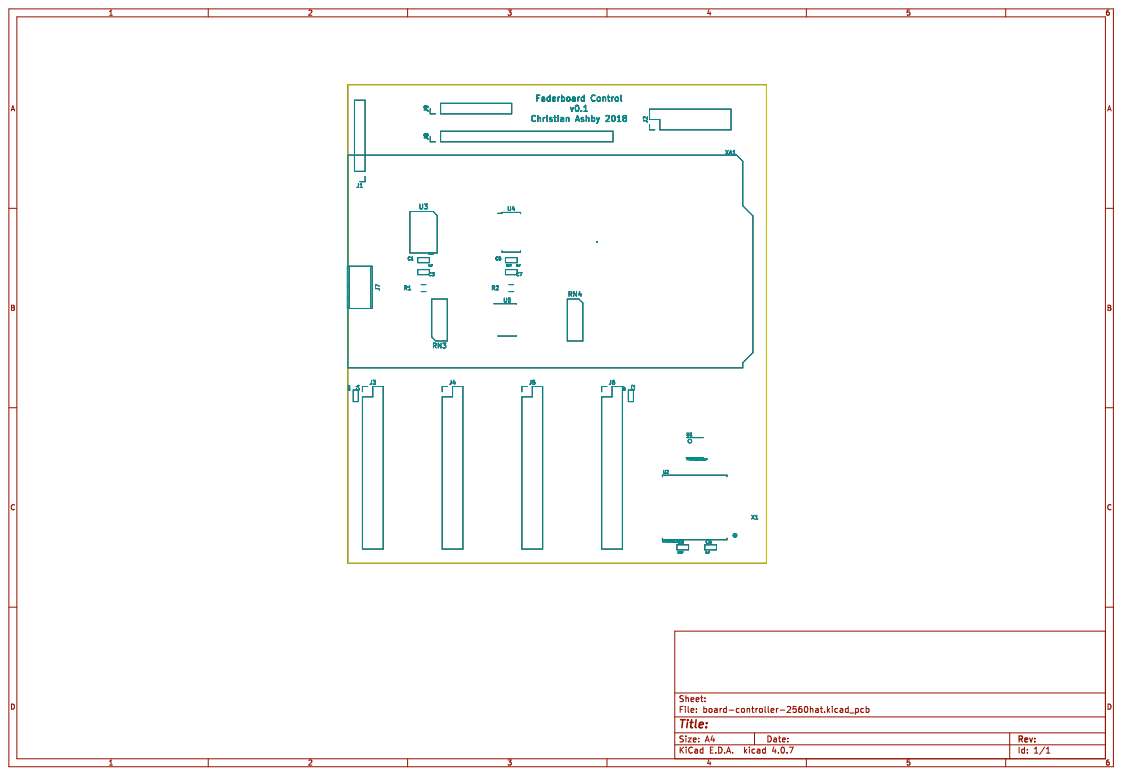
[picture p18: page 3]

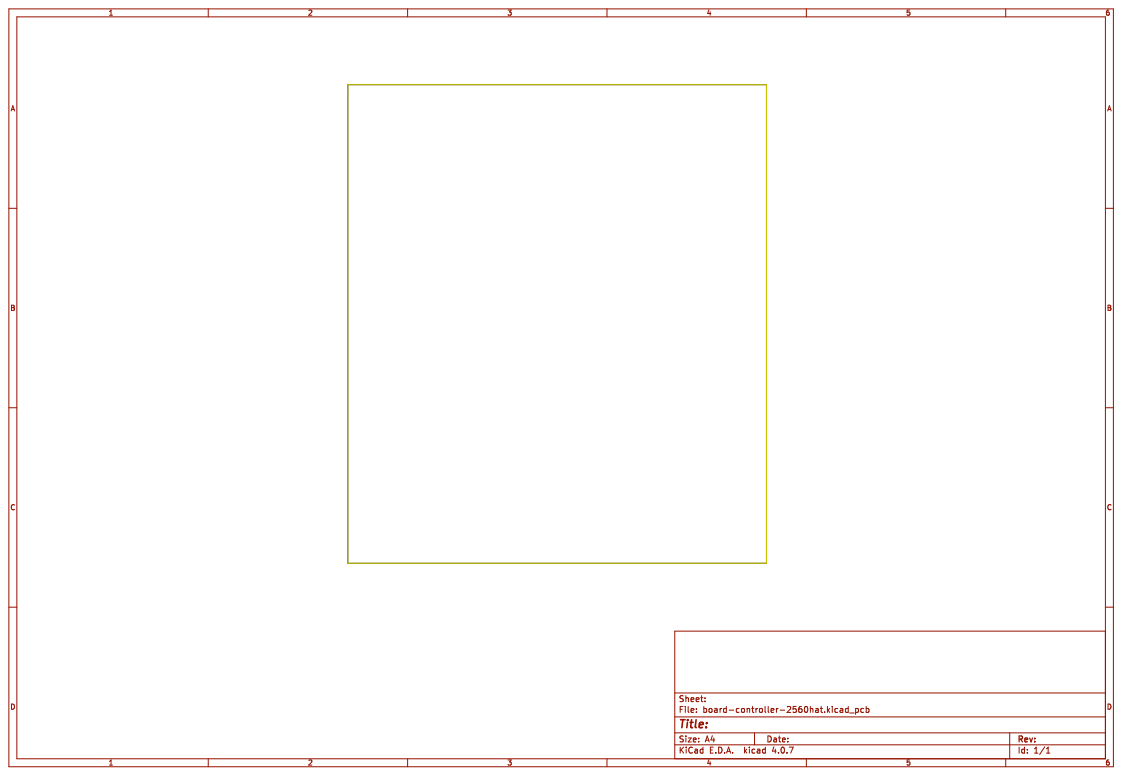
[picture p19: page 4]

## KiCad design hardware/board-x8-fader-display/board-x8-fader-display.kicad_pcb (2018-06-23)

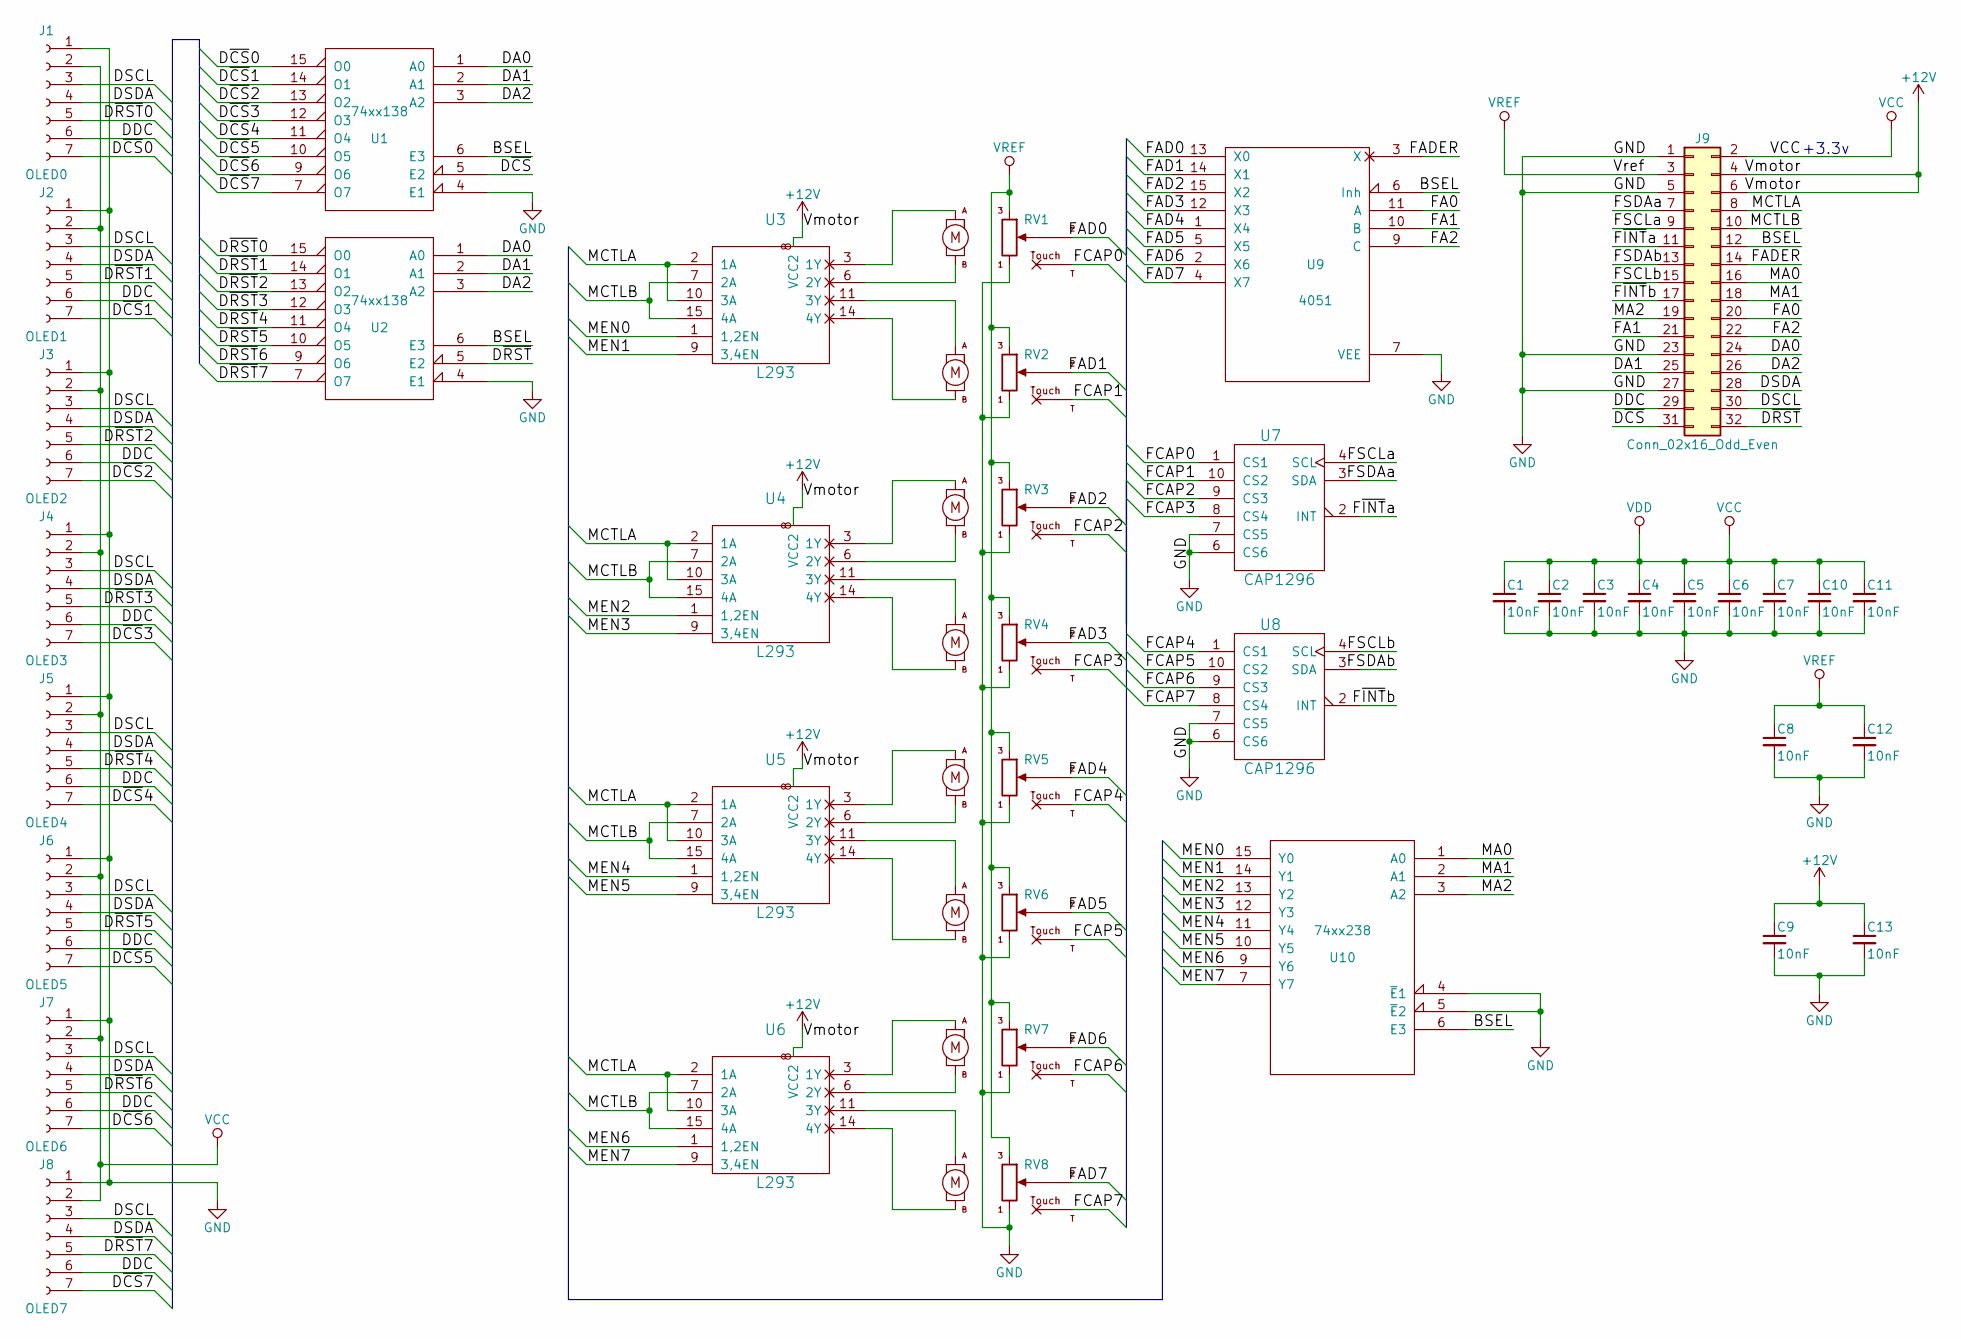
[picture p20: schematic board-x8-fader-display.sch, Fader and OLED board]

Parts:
C1, C2, C3, C4, C5, C6, C7, C8, C9, C10, C11, C12, C13: 10nF; C_Disc_D5.0mm_W2.5mm_P5.00mm
J1: OLED0; 0.95_SPI_SSD1306_Display
J2: OLED1; 0.95_SPI_SSD1306_Display
J3: OLED2; 0.95_SPI_SSD1306_Display
J4: OLED3; 0.95_SPI_SSD1306_Display
J5: OLED4; 0.95_SPI_SSD1306_Display
J6: OLED5; 0.95_SPI_SSD1306_Display
J7: OLED6; 0.95_SPI_SSD1306_Display
J8: OLED7; 0.95_SPI_SSD1306_Display
J9: Conn_02x16_Odd_Even; Pin_Header_Straight_2x16_Pitch2.54mm
RV1, RV2, RV3, RV4, RV5, RV6, RV7, RV8: RSA0N11M9A0J; AlpsFader_RSA0N11M9A0J
U1, U2: 74xx138; DIP-16_W7.62mm
U3, U4, U5, U6: L293; DIP-16_W7.62mm
U7, U8: CAP1296; DFN-10-1EP_3x3mm_Pitch0.5mm
U9: 4051; DIP-16_W7.62mm
U10: 74xx238; DIP-16_W7.62mm

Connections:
+12V: C9.1, C13.1, J9.4, J9.6, U3.8 (VCC2), U4.8 (VCC2), U5.8 (VCC2), U6.8 (VCC2)
/BSEL: J9.12, U1.6 (E3), U2.6 (E3), U9.6 (Inh), U10.6 (E3)
/DA0: J9.24, U1.1 (A0), U2.1 (A0)
/DA1: J9.25, U1.2 (A1), U2.2 (A1)
/DA2: J9.26, U1.3 (A2), U2.3 (A2)
/DDC: J1.6, J2.6, J3.6, J4.6, J5.6, J6.6, J7.6, J8.6, J9.29
/DSCL: J1.3, J2.3, J3.3, J4.3, J5.3, J6.3, J7.3, J8.3, J9.30
/DSDA: J1.4, J2.4, J3.4, J4.4, J5.4, J6.4, J7.4, J8.4, J9.28
/D~CS~: J9.31, U1.5 (E2)
/D~CS~0: J1.7, U1.15 (O0)
/D~CS~1: J2.7, U1.14 (O1)
/D~CS~2: J3.7, U1.13 (O2)
/D~CS~3: J4.7, U1.12 (O3)
/D~CS~4: J5.7, U1.11 (O4)
/D~CS~5: J6.7, U1.10 (O5)
/D~CS~6: J7.7, U1.9 (O6)
/D~CS~7: J8.7, U1.7 (O7)
/D~RST~: J9.32, U2.5 (E2)
/D~RST~0: J1.5, U2.15 (O0)
/D~RST~1: J2.5, U2.14 (O1)
/D~RST~2: J3.5, U2.13 (O2)
/D~RST~3: J4.5, U2.12 (O3)
/D~RST~4: J5.5, U2.11 (O4)
/D~RST~5: J6.5, U2.10 (O5)
/D~RST~6: J7.5, U2.9 (O6)
/D~RST~7: J8.5, U2.7 (O7)
/FA0: J9.20, U9.11 (A)
/FA1: J9.21, U9.10 (B)
/FA2: J9.22, U9.9 (C)
/FAD0: RV1.2, U9.13 (X0)
/FAD1: RV2.2, U9.14 (X1)
/FAD2: RV3.2, U9.15 (X2)
/FAD3: RV4.2, U9.12 (X3)
/FAD4: RV5.2, U9.1 (X4)
/FAD5: RV6.2, U9.5 (X5)
/FAD6: RV7.2, U9.2 (X6)
/FAD7: RV8.2, U9.4 (X7)
/FADER: J9.14, U9.3 (X)
/FCAP0: RV1.T (Touch), U7.1 (CS1)
/FCAP1: RV2.T (Touch), U7.10 (CS2)
/FCAP2: RV3.T (Touch), U7.9 (CS3)
/FCAP3: RV4.T (Touch), U7.8 (CS4)
/FCAP4: RV5.T (Touch), U8.1 (CS1)
/FCAP5: RV6.T (Touch), U8.10 (CS2)
/FCAP6: RV7.T (Touch), U8.9 (CS3)
/FCAP7: RV8.T (Touch), U8.8 (CS4)
/FSCLa: J9.9, U7.4 (SCL)
/FSCLb: J9.15, U8.4 (SCL)
/FSDAa: J9.7, U7.3 (SDA)
/FSDAb: J9.13, U8.3 (SDA)
/F~INT~a: J9.11, U7.2 (INT)
/F~INT~b: J9.17, U8.2 (INT)
/MA0: J9.16, U10.1 (A0)
/MA1: J9.18, U10.2 (A1)
/MA2: J9.19, U10.3 (A2)
/MCTLA: J9.8, U3.2 (1A), U3.10 (3A), U4.2 (1A), U4.10 (3A), U5.2 (1A), U5.10 (3A), U6.2 (1A), U6.10 (3A)
/MCTLB: J9.10, U3.7 (2A), U3.15 (4A), U4.7 (2A), U4.15 (4A), U5.7 (2A), U5.15 (4A), U6.7 (2A), U6.15 (4A)
/MEN0: U3.1 (1,2EN), U10.15 (Y0)
/MEN1: U3.9 (3,4EN), U10.14 (Y1)
/MEN2: U4.1 (1,2EN), U10.13 (Y2)
/MEN3: U4.9 (3,4EN), U10.12 (Y3)
/MEN4: U5.1 (1,2EN), U10.11 (Y4)
/MEN5: U5.9 (3,4EN), U10.10 (Y5)
/MEN6: U6.1 (1,2EN), U10.9 (Y6)
/MEN7: U6.9 (3,4EN), U10.7 (Y7)
GND: C1.2, C2.2, C3.2, C4.2, C5.2, C6.2, C7.2, C8.2, C9.2, C10.2, C11.2, C12.2, C13.2, J1.1, J2.1, J3.1, J4.1, J5.1, J6.1, J7.1, J8.1, J9.1, J9.5, J9.23, J9.27, RV1.3, RV2.3, RV3.3, RV4.3, RV5.3, RV6.3, RV7.3, RV8.3, U1.4 (E1), U1.8 (GND), U2.4 (E1), U2.8 (GND), U3.4 (GND), U3.5 (GND), U3.12 (GND), U3.13 (GND), U4.4 (GND), U4.5 (GND), U4.12 (GND), U4.13 (GND), U5.4 (GND), U5.5 (GND), U5.12 (GND), U5.13 (GND), U6.4 (GND), U6.5 (GND), U6.12 (GND), U6.13 (GND), U7.6 (CS6), U7.7 (CS5), U7.11 (GND), U8.6 (CS6), U8.7 (CS5), U8.11 (GND), U9.7 (VEE), U9.8 (GND), U10.4 (~E~1), U10.5 (~E~2), U10.8 (GND)
unnamed: RV1.A, U3.3 (1Y)
unnamed: RV1.B, U3.6 (2Y)
unnamed: RV2.A, U3.11 (3Y)
unnamed: RV2.B, U3.14 (4Y)
unnamed: RV3.A, U4.3 (1Y)
unnamed: RV3.B, U4.6 (2Y)
unnamed: RV4.A, U4.11 (3Y)
unnamed: RV4.B, U4.14 (4Y)
unnamed: RV5.A, U5.3 (1Y)
unnamed: RV5.B, U5.6 (2Y)
unnamed: RV6.A, U5.11 (3Y)
unnamed: RV6.B, U5.14 (4Y)
unnamed: RV7.A, U6.3 (1Y)
unnamed: RV7.B, U6.6 (2Y)
unnamed: RV8.A, U6.11 (3Y)
unnamed: RV8.B, U6.14 (4Y)
VCC: C1.1, C2.1, C3.1, C4.1, C5.1, C6.1, C7.1, C10.1, C11.1, J1.2, J2.2, J3.2, J4.2, J5.2, J6.2, J7.2, J8.2, J9.2, U1.16 (VCC), U2.16 (VCC), U3.16 (VCC), U4.16 (VCC), U5.16 (VCC), U6.16 (VCC), U7.5 (VDD), U8.5 (VDD), U9.16 (VCC), U10.16 (VCC)
VREF: C8.1, C12.1, J9.3, RV1.1, RV2.1, RV3.1, RV4.1, RV5.1, RV6.1, RV7.1, RV8.1

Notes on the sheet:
+3.3v

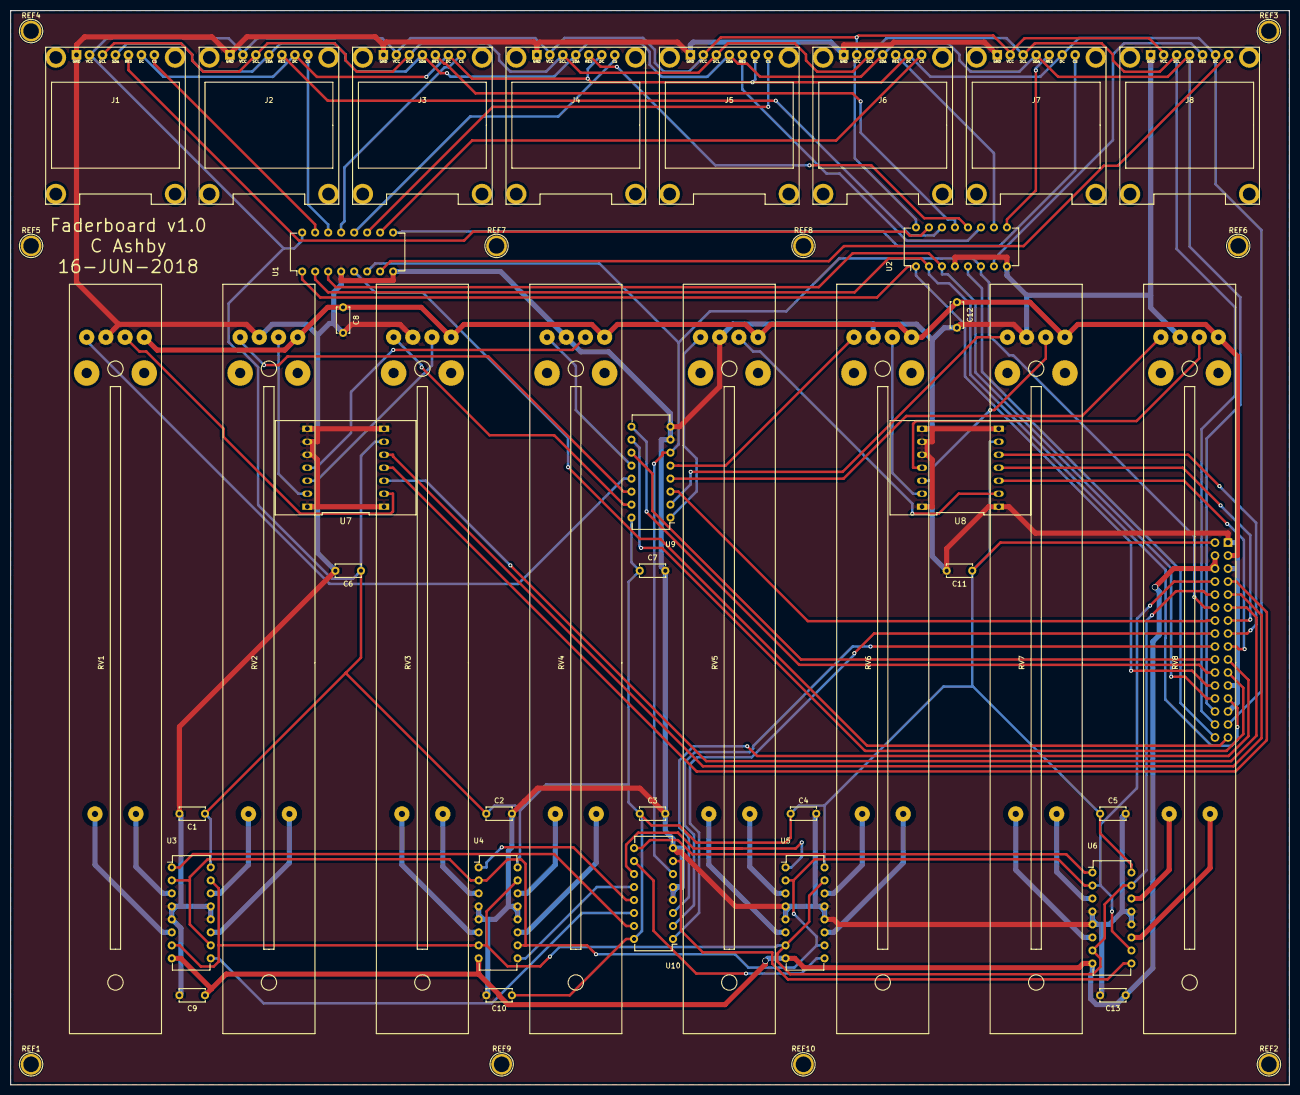
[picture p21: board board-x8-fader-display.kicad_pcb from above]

Board: 2 copper layers, 250.0 x 210.0 mm, 50 parts (1 on the bottom side), 84 nets.

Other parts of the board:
REF1, REF2, REF3, REF4, REF5, REF6, REF7, REF8, REF9, REF10: 1pin

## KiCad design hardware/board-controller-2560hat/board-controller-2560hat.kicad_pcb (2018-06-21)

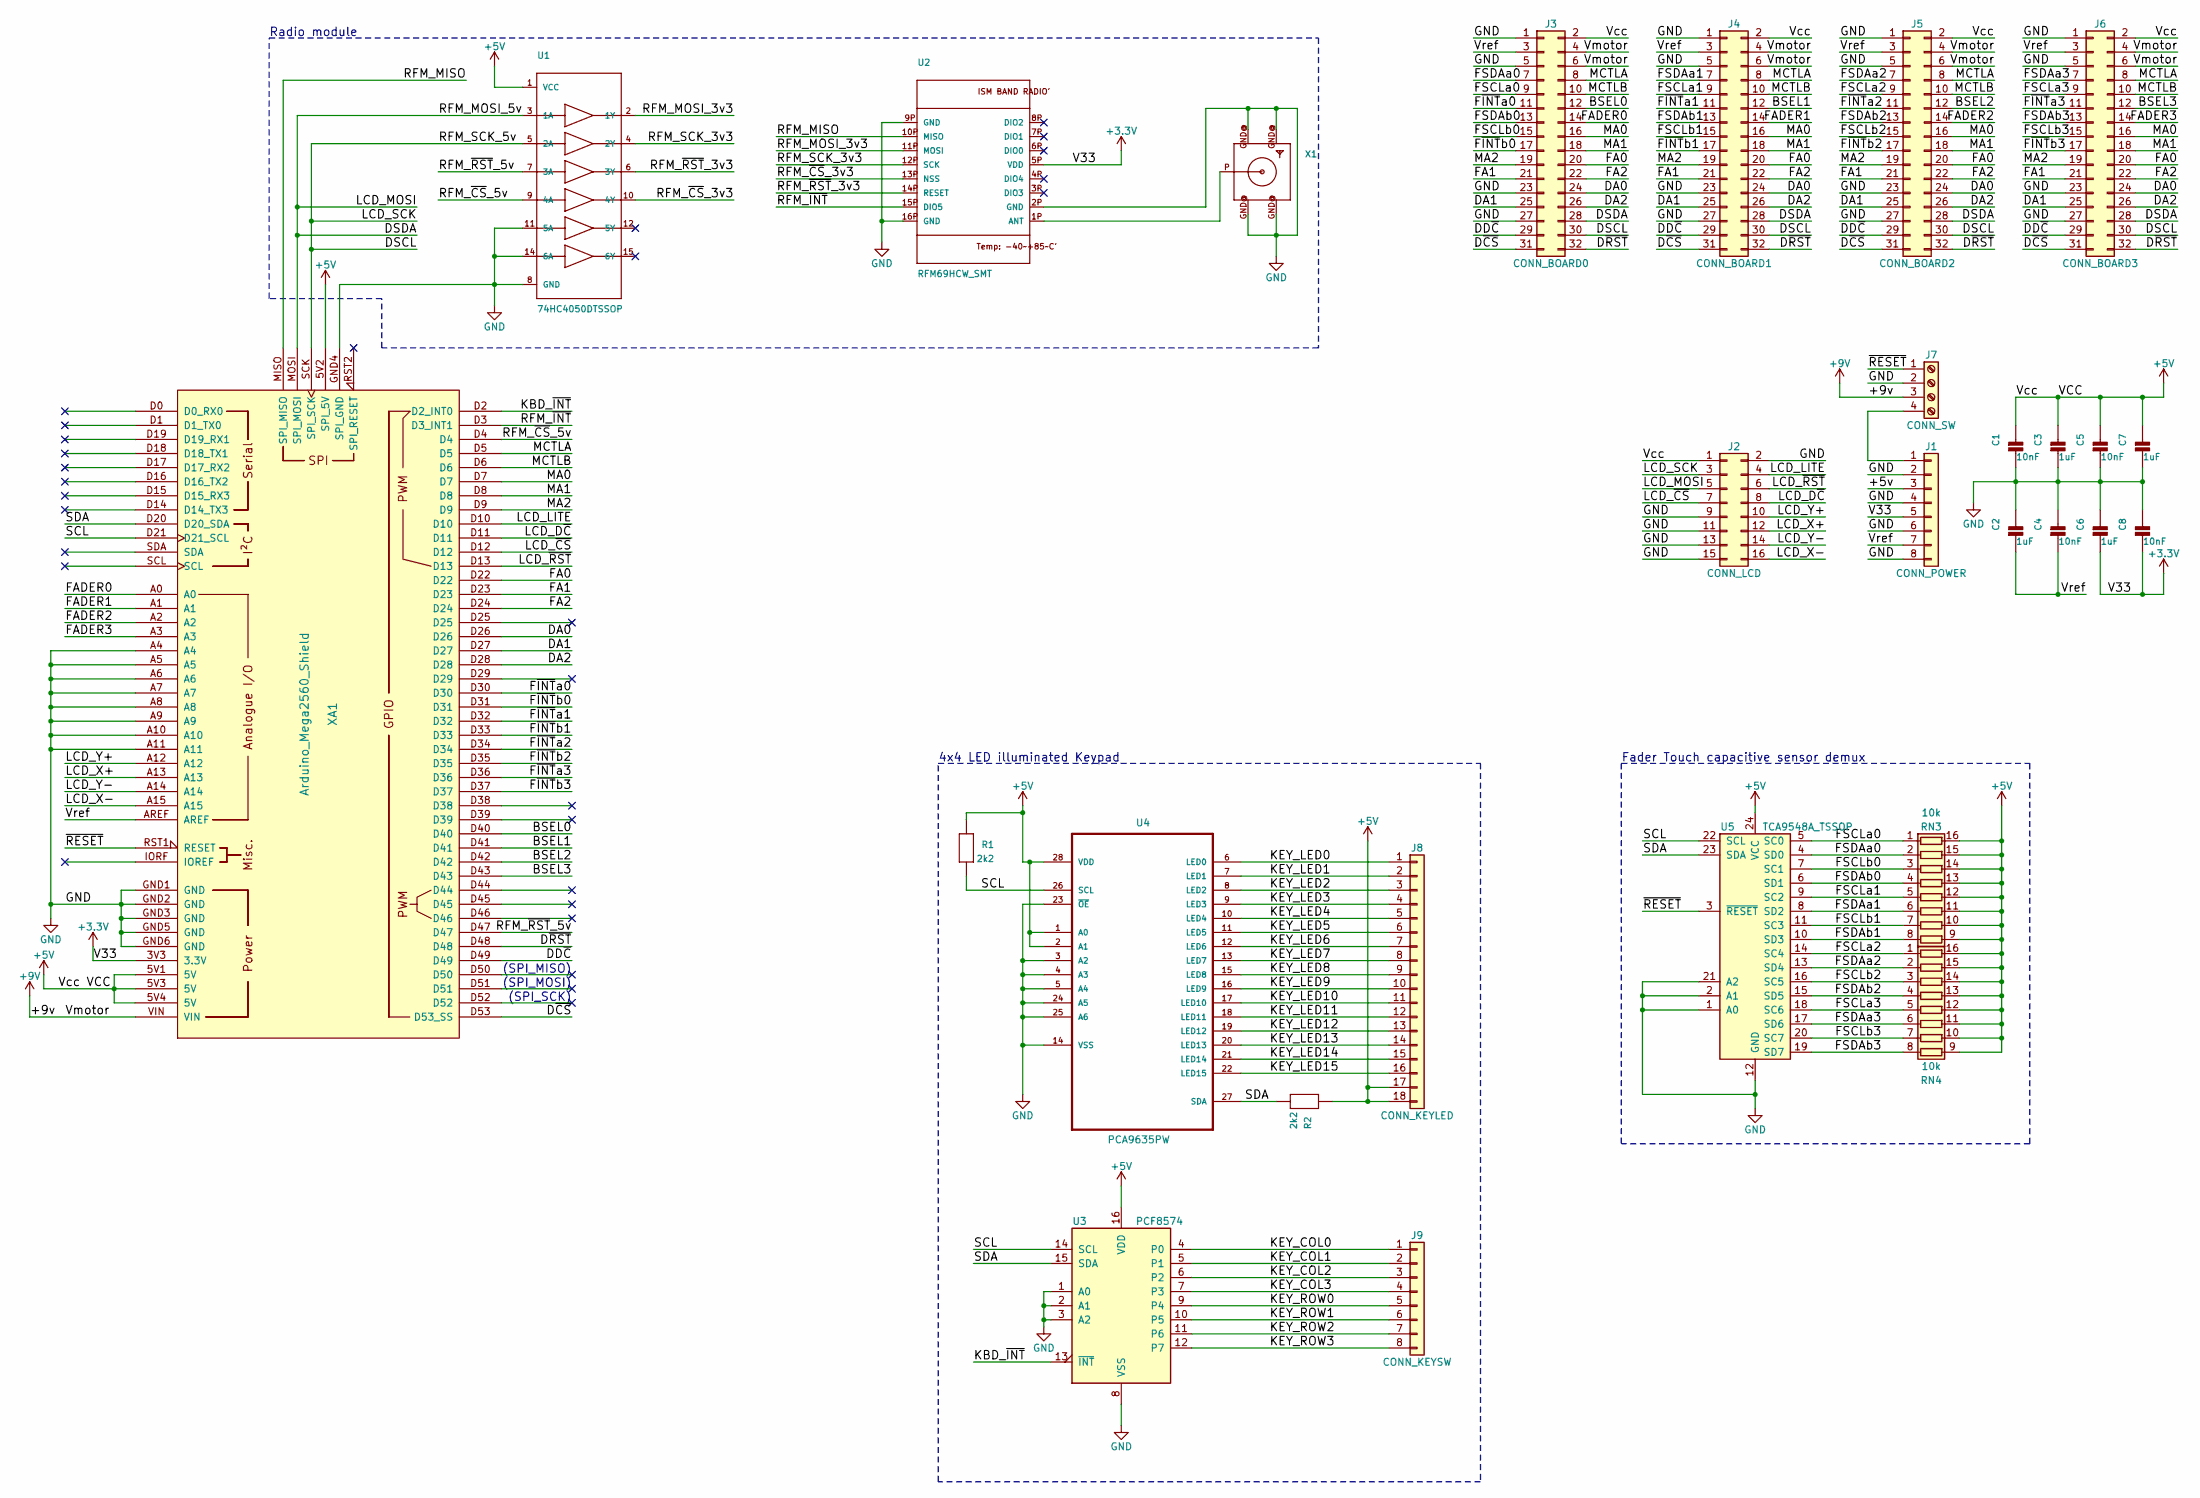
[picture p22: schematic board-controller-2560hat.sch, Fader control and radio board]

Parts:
C1, C4, C5, C8: 10nF; C_0603_HandSoldering
C2, C3, C6, C7: 1uF; C_0603_HandSoldering
J1: CONN_POWER; Pin_Header_Straight_1x08_Pitch2.54mm
J2: CONN_LCD; Pin_Header_Straight_2x08_Pitch2.54mm
J3: CONN_BOARD0; Pin_Header_Straight_2x16_Pitch2.54mm
J4: CONN_BOARD1; Pin_Header_Straight_2x16_Pitch2.54mm
J5: CONN_BOARD2; Pin_Header_Straight_2x16_Pitch2.54mm
J6: CONN_BOARD3; Pin_Header_Straight_2x16_Pitch2.54mm
J7: CONN_SW; TerminalBlock_Pheonix_MPT-2.54mm_4pol
J8: CONN_KEYLED; Pin_Header_Straight_1x18_Pitch2.54mm
J9: CONN_KEYSW; Pin_Header_Straight_1x08_Pitch2.54mm
R1, R2: 2k2; C_1206_HandSoldering
RN3, RN4: 10k; CA_SOIC_16_5.59x11.18_1.27_Pitch
U1: 74HC4050DTSSOP; SSOP-16_5.3x6.2mm_Pitch0.65mm
U2: RFM69HCW_SMT; RFMHCW_SMT
U3: PCF8574; CA_SOIC_16_7.5x10.5_1.27_Pitch
U4: PCA9635PW; TSSOP-28_4.4x9.7mm_Pitch0.65mm
U5: TCA9548A_TSSOP; TSSOP-24_4.4x7.8mm_Pitch0.65mm
X1: SMACONNECTOR_EDGE; SMA_EDGELAUNCH
XA1: Arduino_Mega2560_Shield

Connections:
+3V3: C6.2, C8.2, J1.5, U2.5P (VDD), XA1.3V3 (3.3V)
+5V: C1.1, C3.1, C5.1, C7.1, J1.3, J2.1, J3.2, J4.2, J5.2, J6.2, J8.17, J8.18, R1.2, R2.2, RN3.9 (R8.2), RN3.10 (R7.2), RN3.11 (R6.2), RN3.12 (R5.2), RN3.13 (R4.2), RN3.14 (R3.2), RN3.15 (R2.2), RN3.16 (R1.2), RN4.9 (R8.2), RN4.10 (R7.2), RN4.11 (R6.2), RN4.12 (R5.2), RN4.13 (R4.2), RN4.14 (R3.2), RN4.15 (R2.2), RN4.16 (R1.2), U1.1 (VCC), U3.16 (VDD), U4.1 (A0), U4.2 (A1), U4.28 (VDD), U5.24 (VCC), XA1.5V1 (5V), XA1.5V2 (SPI_5V), XA1.5V3 (5V), XA1.5V4 (5V)
+9V: J3.4, J3.6, J4.4, J4.6, J5.4, J5.6, J6.4, J6.6, J7.3, XA1.VIN
/BSEL0: J3.12, XA1.D40
/BSEL1: J4.12, XA1.D41
/BSEL2: J5.12, XA1.D42
/BSEL3: J6.12, XA1.D43
/DA0: J3.24, J4.24, J5.24, J6.24, XA1.D26
/DA1: J3.25, J4.25, J5.25, J6.25, XA1.D27
/DA2: J3.26, J4.26, J5.26, J6.26, XA1.D28
/DD~C~: J3.29, J4.29, J5.29, J6.29, XA1.D49
/DSCL: J2.3, J3.30, J4.30, J5.30, J6.30, U1.5 (2A), XA1.SCK (SPI_SCK)
/DSDA: J2.5, J3.28, J4.28, J5.28, J6.28, U1.3 (1A), XA1.MOSI (SPI_MOSI)
/D~CS~: J3.31, J4.31, J5.31, J6.31, XA1.D53 (D53_SS)
/D~RST~: J3.32, J4.32, J5.32, J6.32, XA1.D48
/FA0: J3.20, J4.20, J5.20, J6.20, XA1.D22
/FA1: J3.21, J4.21, J5.21, J6.21, XA1.D23
/FA2: J3.22, J4.22, J5.22, J6.22, XA1.D24
/FADER0: J3.14, XA1.A0
/FADER1: J4.14, XA1.A1
/FADER2: J5.14, XA1.A2
/FADER3: J6.14, XA1.A3
/FSCLa0: J3.9, RN3.1 (R1.1), U5.5 (SC0)
/FSCLa1: J4.9, RN3.5 (R5.1), U5.9 (SC2)
/FSCLa2: J5.9, RN4.1 (R1.1), U5.14 (SC4)
/FSCLa3: J6.9, RN4.5 (R5.1), U5.18 (SC6)
/FSCLb0: J3.15, RN3.3 (R3.1), U5.7 (SC1)
/FSCLb1: J4.15, RN3.7 (R7.1), U5.11 (SC3)
/FSCLb2: J5.15, RN4.3 (R3.1), U5.16 (SC5)
/FSCLb3: J6.15, RN4.7 (R7.1), U5.20 (SC7)
/FSDAa0: J3.7, RN3.2 (R2.1), U5.4 (SD0)
/FSDAa1: J4.7, RN3.6 (R6.1), U5.8 (SD2)
/FSDAa2: J5.7, RN4.2 (R2.1), U5.13 (SD4)
/FSDAa3: J6.7, RN4.6 (R6.1), U5.17 (SD6)
/FSDAb0: J3.13, RN3.4 (R4.1), U5.6 (SD1)
/FSDAb1: J4.13, RN3.8 (R8.1), U5.10 (SD3)
/FSDAb2: J5.13, RN4.4 (R4.1), U5.15 (SD5)
/FSDAb3: J6.13, RN4.8 (R8.1), U5.19 (SD7)
/F~INT~a0: J3.11, XA1.D30
/F~INT~a1: J4.11, XA1.D32
/F~INT~a2: J5.11, XA1.D34
/F~INT~a3: J6.11, XA1.D36
/F~INT~b0: J3.17, XA1.D31
/F~INT~b1: J4.17, XA1.D33
/F~INT~b2: J5.17, XA1.D35
/F~INT~b3: J6.17, XA1.D37
/KBD_~INT~: U3.13 (~INT~), XA1.D2 (D2_INT0)
/KEY_COL0: J9.1, U3.4 (P0)
/KEY_COL1: J9.2, U3.5 (P1)
/KEY_COL2: J9.3, U3.6 (P2)
/KEY_COL3: J9.4, U3.7 (P3)
/KEY_LED0: J8.1, U4.6 (LED0)
/KEY_LED1: J8.2, U4.7 (LED1)
/KEY_LED2: J8.3, U4.8 (LED2)
/KEY_LED3: J8.4, U4.9 (LED3)
/KEY_LED4: J8.5, U4.10 (LED4)
/KEY_LED5: J8.6, U4.11 (LED5)
/KEY_LED6: J8.7, U4.12 (LED6)
/KEY_LED7: J8.8, U4.13 (LED7)
/KEY_LED8: J8.9, U4.15 (LED8)
/KEY_LED9: J8.10, U4.16 (LED9)
/KEY_LED10: J8.11, U4.17 (LED10)
/KEY_LED11: J8.12, U4.18 (LED11)
/KEY_LED12: J8.13, U4.19 (LED12)
/KEY_LED13: J8.14, U4.20 (LED13)
/KEY_LED14: J8.15, U4.21 (LED14)
/KEY_LED15: J8.16, U4.22 (LED15)
/KEY_ROW0: J9.5, U3.9 (P4)
/KEY_ROW1: J9.6, U3.10 (P5)
/KEY_ROW2: J9.7, U3.11 (P6)
/KEY_ROW3: J9.8, U3.12 (P7)
/LCD_D~C~: J2.8, XA1.D11
/LCD_LITE: J2.4, XA1.D10
/LCD_X+: J2.12, XA1.A13
/LCD_X-: J2.16, XA1.A15
/LCD_Y+: J2.10, XA1.A12
/LCD_Y-: J2.14, XA1.A14
/LCD_~CS~: J2.7, XA1.D12
/LCD_~RST~: J2.6, XA1.D13
/MA0: J3.16, J4.16, J5.16, J6.16, XA1.D7
/MA1: J3.18, J4.18, J5.18, J6.18, XA1.D8
/MA2: J3.19, J4.19, J5.19, J6.19, XA1.D9
/MCTLA: J3.8, J4.8, J5.8, J6.8, XA1.D5
/MCTLB: J3.10, J4.10, J5.10, J6.10, XA1.D6
/RFM_MISO: U2.10P (MISO), XA1.MISO (SPI_MISO)
/RFM_MOSI_3v3: U1.2 (1Y), U2.11P (MOSI)
/RFM_SCK_3v3: U1.4 (2Y), U2.12P (SCK)
/RFM_~CS~_3v3: U1.10 (4Y), U2.13P (NSS)
/RFM_~CS~_5v: U1.9 (4A), XA1.D4
/RFM_~INT~: U2.15P (DIO5), XA1.D3 (D3_INT1)
/RFM_~RST~_3v3: U1.6 (3Y), U2.14P (RESET)
/RFM_~RST~_5v: U1.7 (3A), XA1.D47
/SCL: R1.1, U3.14 (SCL), U4.26 (SCL), U5.22 (SCL), XA1.D21 (D21_SCL)
/SDA: R2.1, U3.15 (SDA), U4.27 (SDA), U5.23 (SDA), XA1.D20 (D20_SDA)
/Vref: C2.2, C4.2, J1.7, J3.3, J4.3, J5.3, J6.3, XA1.AREF
/~RESET~: J7.1, U5.3 (~RESET), XA1.RST1 (RESET)
GND: C1.2, C2.1, C3.2, C4.1, C5.2, C6.1, C7.2, C8.1, J1.2, J1.4, J1.6, J1.8, J2.2, J2.9, J2.11, J2.13, J2.15, J3.1, J3.5, J3.23, J3.27, J4.1, J4.5, J4.23, J4.27, J5.1, J5.5, J5.23, J5.27, J6.1, J6.5, J6.23, J6.27, J7.2, U1.8 (GND), U1.11 (5A), U1.14 (6A), U2.2P (GND), U2.9P (GND), U2.16P (GND), U3.1 (A0), U3.2 (A1), U3.3 (A2), U3.8 (VSS), U4.3 (A2), U4.4 (A3), U4.5 (A4), U4.14 (VSS), U4.23 (~OE), U4.24 (A5), U4.25 (A6), U5.1 (A0), U5.2 (A1), U5.12 (GND), U5.21 (A2), X1.GND@ (GND1), XA1.A4, XA1.A5, XA1.A6, XA1.A7, XA1.A8, XA1.A9, XA1.A10, XA1.A11, XA1.GND1 (GND), XA1.GND2 (GND), XA1.GND3 (GND), XA1.GND4 (SPI_GND), XA1.GND5 (GND), XA1.GND6 (GND)
unnamed: J1.1, J7.4
unnamed: U2.1P (ANT), X1.P (ANT)

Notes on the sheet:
Fader Touch capacitive sensor demux
Radio module
4x4 LED illuminated Keypad
(SPI_MOSI)
(SPI_MISO)
(SPI_SCK)

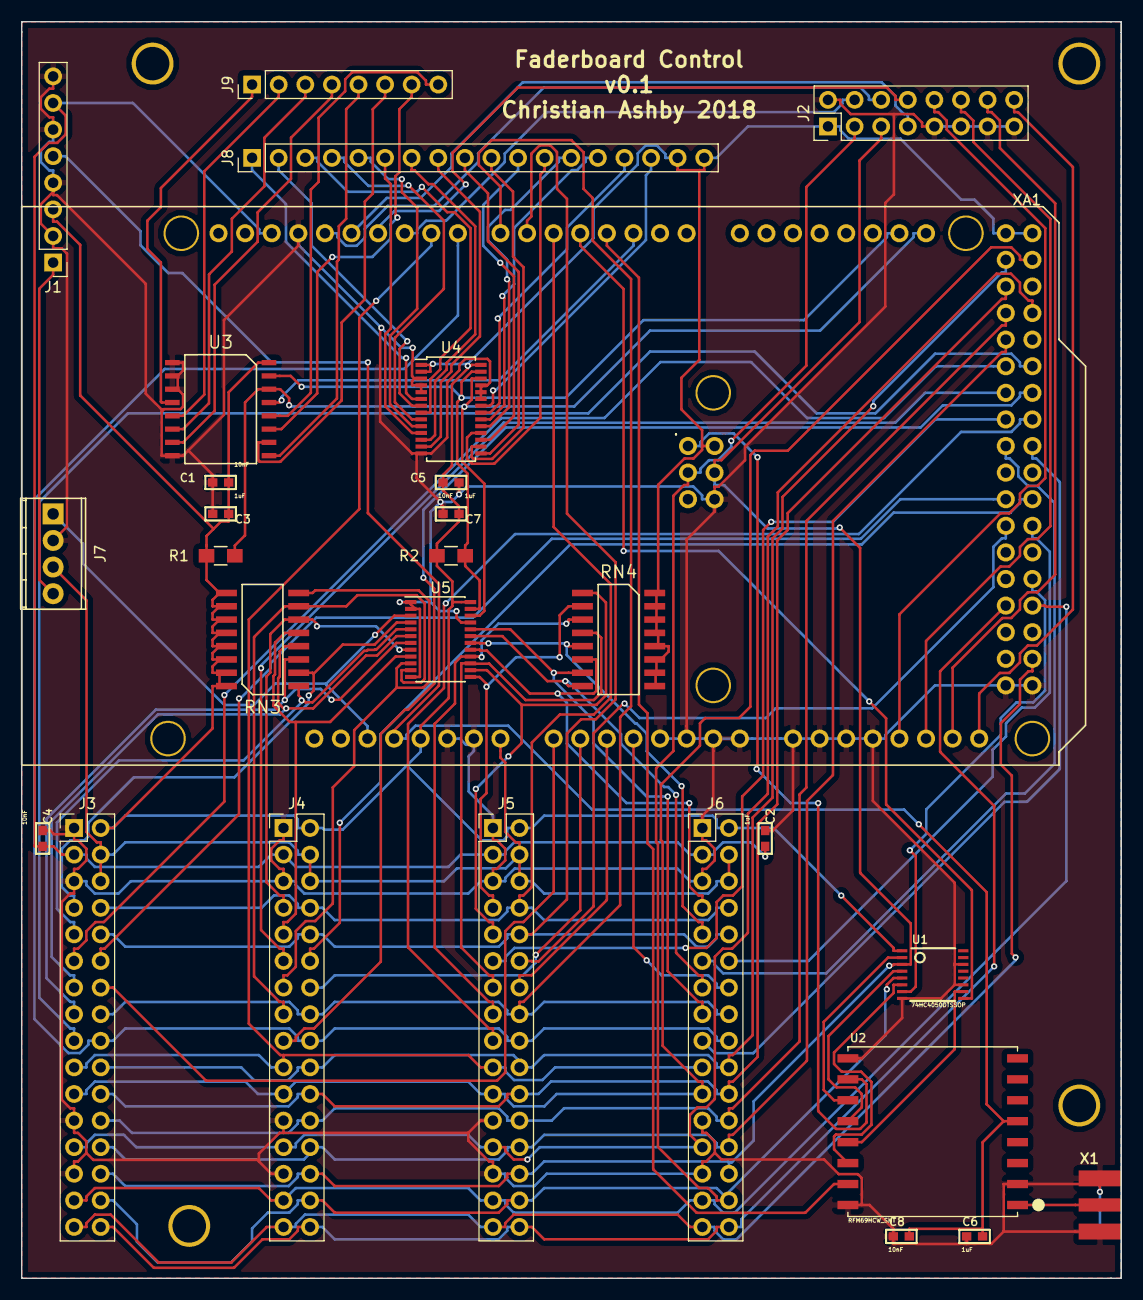
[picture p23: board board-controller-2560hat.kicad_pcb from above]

Board: 2 copper layers, 105.0 x 120.0 mm, 28 parts (0 on the bottom side), 99 nets.

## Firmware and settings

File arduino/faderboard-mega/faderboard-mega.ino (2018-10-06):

// General libraries
#include <SPI.h>

// Radio libraries
#include <RFM69.h>
//#include <RFM69_ATC.h>

// Libraries for displays
#include <Adafruit_GFX.h>
#include <Adafruit_SSD1331.h>
#include <Adafruit_HX8357.h>

#include "MemoryFree.h"
#include "stringutils.h"

#define SERIAL_BAUD   115200

#define LOOP_WAIT     100

// This code only supports one board at the moment. BSEL goes high to enable it.
#define BOARD_SELECT  0

// Wait time between BSEL actions (for enable pins to get high/low enough)
#define DELAY_BSEL    1

// Debugging to avoid LCD/DISPLAY/RADIO if not needed
#define USE_RADIO     0
#define USE_DISPLAYS  0
#define USE_TFT       0

// Board select pins
const byte boardAddressPins[] = { 40,41,42,43 };

// Radio assignments
#define RADIO_CS      4
#define RADIO_RST     2
#define RADIO_INT     3
#define RADIO_BAND    RF69_433MHZ

// Uncomment if this board is the RFM69HW/HCW not the RFM69W/CW
#define RADIO_IS_RFM69HW_HCW

#define RADIO_MYID    2
#define RADIO_DESKID  1
#define RADIO_NETID   100

// Maximum number of times re try to send a batch of fader levels
#define RADIO_MAXRETRIES      1
// Current try count - -1 = not changed
int radio_sendtries = 0;
// Singleton RF69 object
RFM69 radio(RADIO_CS, RADIO_INT, false);

// Pin assignments
// - TODO: Make these one, but I'm testing with random numbers of things populated
#define DISPLAY_COUNT 4
#define FADER_COUNT   8

#define DISPLAY_CS    53
#define DISPLAY_RST   48
#define DISPLAY_DC    49
#define MOTOR_CTLA    5
#define MOTOR_CTLB    6
#define TFT_LITE      10
#define TFT_DC        11
#define TFT_CS        12
#define TFT_RST       13

// Singleton TFT object
Adafruit_HX8357 tft = Adafruit_HX8357(TFT_CS, TFT_DC, TFT_RST);

// Need to check what's best for OSC here
#define FADER_NOTSENT 0
#define FADER_MIN     1
#define FADER_MAX     255

// Only send if fader changes by...
#define SEND_THRESHOLD 4

const byte displayAddressPins[] = {26,27,28};
const byte motorAddressPins[] = {7,8,9};
const byte faderAddressPins[] = {22,23,24};
const byte MApins[] = {7,8,9};

const byte faderAnaloguePins[] = {A0,A1,A2,A3};

// Constants
// - Time to wait for motor to move measurably
#define MOTOR_WAIT     20

#define MOTOR_FORWARD  1
#define MOTOR_BACKWARD 0

// - TFT rotation
#define TFT_ROTATION   3

// Uncomment this for faders to calibrate using motors
// - if commented, picks a guess (below) for max / min (quieter and quicker)
// - faders will calibrate first time they're used
#define MOTOR_CALIBRATE

#define MOTOR_DEFAULTMIN  900
#define MOTOR_DEFAULTMAX  100

double fadersMin[FADER_COUNT];
double fadersMax[FADER_COUNT];
// Storage for fader values sent via radio
byte sentFaderVal[FADER_COUNT];

// Display color definitions
#define BLACK           0x0000
#define BLUE            0x001F
#define RED             0xF800
#define GREEN           0x07E0
#define CYAN            0x07FF
#define MAGENTA         0xF81F
#define YELLOW          0xFFE0  
#define WHITE           0xFFFF

Adafruit_SSD1331* displays[DISPLAY_COUNT];

void setup() {
  Serial.begin(SERIAL_BAUD);
  if( Serial ) Serial.println("START");

  // Board select
  pinMode(boardAddressPins[BOARD_SELECT],OUTPUT);
  digitalWrite(boardAddressPins[BOARD_SELECT], HIGH);
  delay(DELAY_BSEL);

  // Initialise LoRa radio stuff
  if( USE_RADIO > 0 ) initRadio();
  // Initialise fader motors
  initFaders();
  // Initialise displays (scribble strips)
  initDisplays();
  // Initialise TFT
  initTFT();
}

// Main loop
void loop() {
  Adafruit_SSD1331* currentDisplay;
  byte faderVal[FADER_COUNT];
  for( byte fader = 0; fader < FADER_COUNT; fader++ ) {
    faderVal[fader] = faderRead(fader);
    if( fader < DISPLAY_COUNT ) {
      currentDisplay = getDisplay(fader);
      currentDisplay->setTextSize(2);
      currentDisplay->setCursor(0,35);
      currentDisplay->setTextColor(RED, BLACK);
      currentDisplay->print(faderVal[fader]);
      currentDisplay->print("   ");
    }
    // If we're not in a retry loop and the fader values have changed then we need to send some data
    if( USE_RADIO > 0 && radio_sendtries == -1 && (faderVal[fader] < ( sentFaderVal[fader] - SEND_THRESHOLD ) || faderVal[fader] > ( sentFaderVal[fader] + SEND_THRESHOLD )) ) {
      radio_sendtries = 0;
    }
    if (Serial) Serial.print("Faders: ");
    if (Serial) Serial.print(faderVal[fader]);
    if( Serial && fader - 1 < FADER_COUNT ) Serial.print(",");
  }
  if (Serial) Serial.println(".");

  tft.setCursor(0, 20);
  for( byte fader = 0; fader < FADER_COUNT; fader++ ) {
    tft.setTextColor(HX8357_RED, HX8357_BLACK);
    tft.setTextSize(2);
    tft.print(u2s(faderVal[fader], 3));
    tft.print(" ");
  }

  if( radio_sendtries > -1 ) {
    if (Serial) Serial.print(radio_sendtries);
    if (Serial) Serial.print(" tries: Sending ");
    byte payload[FADER_COUNT];
    for( byte fader = 0; fader < FADER_COUNT; fader++ ) {
      payload[fader] = faderVal[fader];
      if (Serial) Serial.print(faderVal[fader]);
      if( Serial && fader - 1 < FADER_COUNT ) Serial.print(",");
    }
    if (radio.sendWithRetry(RADIO_DESKID, payload, sizeof(payload), 1, 400)) {
      if (Serial) Serial.println("... ACK received");
      for( byte fader = 0; fader < FADER_COUNT; fader++ ) {
        payload[fader] = faderVal[fader];
        // Register these values as sent
        sentFaderVal[fader] = faderVal[fader];
      }
      radio_sendtries = -1;
    } else {
      radio_sendtries++;
      if (Serial) Serial.print("... No ACK ");
      if (Serial) Serial.print(radio_sendtries);
      if (Serial) Serial.println(" retries");
      // We give up if we have tried too often, but we'll try again when the fader next changes
      if( radio_sendtries >= RADIO_MAXRETRIES ) radio_sendtries = -1;
      for( byte fader = 0; fader < FADER_COUNT; fader++ ) {
        sentFaderVal[fader] = faderVal[fader];
      }
    }
  }

  delay(LOOP_WAIT);
}

void initRadio() {
  // Reset the radio
  if( Serial ) Serial.print("Resetting radio...");
  pinMode(RADIO_RST, OUTPUT);
  digitalWrite(RADIO_RST, HIGH);
  delay(20);
  digitalWrite(RADIO_RST, LOW);
  delay(500);
  // Initialize the radio
  radio.initialize(RADIO_BAND, RADIO_MYID, RADIO_NETID);
  radio.promiscuous(true);
  #ifdef RADIO_IS_RFM69HW_HCW
    radio.setHighPower(); //must include this only for RFM69HW/HCW!
  #endif
  if( Serial ) Serial.println(" Radio ready");
}

void initDisplays() {
  if( Serial ) Serial.print("Display initialisation...");
  // - set DA pins as output
  setModeOfPins(displayAddressPins, OUTPUT);
  for( byte fader = 0; fader < DISPLAY_COUNT; fader++ ) {
    for( int bt=0; bt<=sizeof(displayAddressPins); bt++ ) {
      byte state = bitRead(fader, bt);
      digitalWrite(displayAddressPins[bt], state);
    }
    Adafruit_SSD1331* currentDisplay = new Adafruit_SSD1331(DISPLAY_CS, DISPLAY_DC, DISPLAY_RST);
    displays[fader] = currentDisplay;
    currentDisplay->begin();
    currentDisplay->fillScreen(BLACK);
    currentDisplay->setTextColor(BLUE);
    currentDisplay->setTextSize(3);
    currentDisplay->println(fader);
    currentDisplay->setTextSize(1);
    currentDisplay->print(fadersMin[fader]); currentDisplay->print(" - "); currentDisplay->print(fadersMax[fader]);
  }
  if( Serial ) Serial.println(" Displays ready");
}

Adafruit_SSD1331* getDisplay(byte fader) {
  for( int bt=0; bt<=sizeof(displayAddressPins); bt++ ) {
    byte state = bitRead(fader, bt);
    digitalWrite(displayAddressPins[bt], state);
  }
  return displays[fader];
}

void initTFT() {
  if( Serial ) Serial.print("TFT initialisation...");

  pinMode(TFT_LITE, OUTPUT);
  // TODO: Support PWM for LCD backlight
  digitalWrite(TFT_LITE, HIGH);

  tft.begin(HX8357D);
  tft.setRotation(TFT_ROTATION);
  
  tft.fillScreen(HX8357_BLACK);

  tft.setCursor(0, 0);
  tft.setTextColor(HX8357_WHITE);  tft.setTextSize(1);
  tft.println("Ready");

  if( Serial ) Serial.println(" TFT ready");
}

void initFaders() {
  if( Serial ) Serial.println("Motor initialisation...");
  pinMode(MOTOR_CTLA,OUTPUT);
  pinMode(MOTOR_CTLB,OUTPUT);
  setModeOfPins(motorAddressPins, OUTPUT);
  setModeOfPins(faderAddressPins, OUTPUT);
#ifdef MOTOR_CALIBRATE
  // - calibration
  //   - before / after fader variables to check if stopped moving
  double a,b;
  for( byte fader = 0; fader < FADER_COUNT; fader++ ) {
    sentFaderVal[fader] = FADER_NOTSENT;
    a = 0; b = 10;
    // - motor could be anywhere so go down first
    motorMove(fader, MOTOR_BACKWARD);
    while( a != b ) {
      a = faderReadRAW(fader);
      delay(MOTOR_WAIT);
      b = faderReadRAW(fader);
      //if( Serial ) Serial.print(fader); if( Serial ) Serial.print(" 1 "); if( Serial ) Serial.print(a); if( Serial ) Serial.print(","); if( Serial ) Serial.println(b);
    }
    a = 0; b = 10;
    motorMove(fader, MOTOR_FORWARD);
    while( a != b ) {
      a = faderReadRAW(fader);
      delay(MOTOR_WAIT);
      b = faderReadRAW(fader);
      //if( Serial ) Serial.print(fader); if( Serial ) Serial.print(" 2 "); if( Serial ) Serial.print(a); if( Serial ) Serial.print(","); if( Serial ) Serial.println(b);
    }
    fadersMax[fader] = faderReadRAW(fader);
    motorStop(fader);
    motorMove(fader, MOTOR_BACKWARD);
    a = 0; b = 10;
    while( a != b ) {
      a = faderReadRAW(fader);
      delay(MOTOR_WAIT);
      b = faderReadRAW(fader);
      //if( Serial ) Serial.print(fader); if( Serial ) Serial.print(" 3 "); if( Serial ) Serial.print(a); if( Serial ) Serial.print(","); if( Serial ) Serial.println(b);
    }
    fadersMin[fader] = faderReadRAW(fader);
    motorStop(fader);
    if( Serial ) Serial.print("- calibrate fader "); if( Serial ) Serial.print(fader); if( Serial ) Serial.print(": "); if( Serial ) Serial.print(fadersMin[fader]); if( Serial ) Serial.print(" to "); if( Serial ) Serial.println(fadersMax[fader]);
  }
#else
  for( byte fader = 0; fader < FADER_COUNT; fader++ ) {
    fadersMin[fader] = MOTOR_DEFAULTMIN;
    fadersMax[fader] = MOTOR_DEFAULTMAX;
  }
#endif
  if( Serial ) Serial.println(" Motors ready");
}

void setModeOfPins(byte pins[], int mode) {
  // TODO: Why do I need <= here and < in the ones which use a default array #confused
  for( int pin=0; pin <= sizeof(pins); pin++ ) {
    //if( Serial ) Serial.print("Pin Mode "); if( Serial ) Serial.print(pins[pin]); if( Serial ) Serial.print(" to "); if( Serial ) Serial.println(mode);
    pinMode(pins[pin], mode);
  }
}

void motorSelect(byte fader) {
  for( int bt=0; bt<sizeof(motorAddressPins); bt++ ) {
    byte state = bitRead(fader, bt);
    //if( Serial ) Serial.print("Pin "); if( Serial ) Serial.print(motorAddressPins[bt]); if( Serial ) Serial.print(" to "); if( Serial ) Serial.println(state);
    digitalWrite(motorAddressPins[bt], state);
  }
}

void motorMove(byte fader, byte dir) {
  motorSelect(fader);
  digitalWrite(MOTOR_CTLA,(dir == MOTOR_FORWARD ? HIGH : LOW));
  digitalWrite(MOTOR_CTLB,(dir == MOTOR_FORWARD ? LOW : HIGH));
}

void motorStop(byte fader) {
  motorSelect(fader);
  digitalWrite(MOTOR_CTLA,LOW);
  digitalWrite(MOTOR_CTLB,LOW);  
}

void faderSelect(byte fader) {
  for( int bt=0; bt<sizeof(faderAddressPins); bt++ ) {
    byte state = bitRead(fader, bt);
    digitalWrite(faderAddressPins[bt], state);
  }
}

double faderReadRAW(byte fader) {
  faderSelect(fader);
  // TODO: Fix this in hardware - BSEL should be active HIGH for all chips on the fader boards
  digitalWrite(boardAddressPins[BOARD_SELECT], LOW);
  delay(DELAY_BSEL);
  int val = analogRead(faderAnaloguePins[BOARD_SELECT]);
  // TODO: Fix this in hardware - BSEL should be active HIGH for all chips on the fader boards
  digitalWrite(boardAddressPins[BOARD_SELECT], HIGH);
  delay(DELAY_BSEL);
  return val;
}

byte faderRead(byte fader) {
  faderSelect(fader);
  // TODO: Fix this in hardware - BSEL should be active HIGH for all chips on the fader boards
  digitalWrite(boardAddressPins[BOARD_SELECT], LOW);
  delay(DELAY_BSEL);
  double val = analogRead(faderAnaloguePins[BOARD_SELECT]);
  // TODO: Fix this in hardware - BSEL should be active HIGH for all chips on the fader boards
  digitalWrite(boardAddressPins[BOARD_SELECT], HIGH);
  delay(DELAY_BSEL);
  if( fadersMin[fader] < fadersMax[fader] ) {
    if( val < fadersMin[fader] ) {
      fadersMin[fader] = val;
    } else if( val > fadersMax[fader] ) { 
      fadersMax[fader] = val;
    }
  } else {
    if( val > fadersMin[fader] ) {
      fadersMin[fader] = val;
    } else if( val < fadersMax[fader] ) {
      fadersMax[fader] = val;
    }
  }
  return map(val, fadersMin[fader], fadersMax[fader], FADER_MIN, FADER_MAX);
}

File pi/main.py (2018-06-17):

#!/usr/bin/env python2

import OSC
import RFM69
from RFM69registers import *
import datetime
import time
import traceback

node_id = 1
network_id = 100
recipient_id = 2

# https://stackoverflow.com/questions/929103/convert-a-number-range-to-another-range-maintaining-ratio
def remap( x, oMin, oMax, nMin, nMax ):
    #range check
    if oMin == oMax:
        print "Warning: Zero input range"
        return None

    if nMin == nMax:
        print "Warning: Zero output range"
        return None

    #check reversed input range
    reverseInput = False
    oldMin = min( oMin, oMax )
    oldMax = max( oMin, oMax )
    if not oldMin == oMin:
        reverseInput = True

    #check reversed output range
    reverseOutput = False   
    newMin = min( nMin, nMax )
    newMax = max( nMin, nMax )
    if not newMin == nMin :
        reverseOutput = True

    portion = (x-oldMin)*(newMax-newMin)/(oldMax-oldMin)
    if reverseInput:
        portion = (oldMax-x)*(newMax-newMin)/(oldMax-oldMin)

    result = portion + newMin
    if reverseOutput:
        result = newMax - portion

    return result

if __name__ == '__main__':
    import argparse

    parser = argparse.ArgumentParser(description="TODO")
    parser.add_argument('--address', default="172.16.10.51",                          
                        help='name/ip-address of Behringer X32 mixing desk')

    args = parser.parse_args()

    osc_client = OSC.OSCClient() #TODO: Refer to server when we have one
    osc_client.connect((args.address, 10023))
    osc_client.send(OSC.OSCMessage("/ch/01/mix/fader", [0.0]))
    time.sleep(1)
    osc_client.send(OSC.OSCMessage("/ch/01/mix/fader", [1.0]))
    time.sleep(1)
    osc_client.send(OSC.OSCMessage("/ch/01/mix/fader", [0.0]))
        
    radio = RFM69.RFM69(RF69_433MHZ, node_id, network_id, True)
    print "class initialized"
    #print "reading all registers"
    #results = radio.readAllRegs()
    #for result in results:
    #    print result
    print "Performing rcCalibration"
    radio.rcCalibration()
    print "setting high power"
    radio.setHighPower(True)
    print "Checking temperature"
    print radio.readTemperature(0)
    #print "setting encryption"
    #radio.encrypt("1234567891011121")
    #print "sending blah to 2"
    #if radio.sendWithRetry(2, "blah", 3, 20):
    #    print "ack recieved"
    print "reading"
    try:
        while True:
            radio.receiveBegin()
            while not radio.receiveDone():
                time.sleep(.1)
            data = radio.DATA
            print "%s from %s RSSI:%s" % (",".join([str(b).zfill(3) for b in data]), radio.SENDERID, radio.RSSI)
            i = 1
            debug = ""
            for b in data:
                message = "/ch/" + str(i).zfill(2) + "/mix/fader"
                val = [remap(b, 1, 255, 0.0, 1.0)]
                debug += " " +  str(i) + ":" + message + "=" + str(val)
                osc_client.send(OSC.OSCMessage(message, val))
                i += 1
            print debug
            if radio.ACKRequested():
                radio.sendACK()
    
    except KeyboardInterrupt:
        print "Exit"
    
    except Exception, err:
        traceback.print_exc()
    
    finally:
        print "shutting down"
        radio.shutdown()

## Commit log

2018-01-03 First add - version for faders only (no buttons) and wrong headers
    [Main.sch]
2018-01-03 PDF schematic (WIP like everything else)
2018-01-03 Removed wrong headers, fixed V33 vs VCC mapping
    [Main.sch]
2018-01-27 Pre-tidy folder structure
    [Faderboard.kicad_pcb, Faderboard.sch, Main.sch]
2018-01-27 Cleaning up old schematics
    [Faderboard.kicad_pcb, Faderboard.sch, Main.sch]
2018-01-27 Added fader details and schematic file
    [board-x8-fader-display.kicad_pcb, board-x8-fader-display.sch]
2018-01-27 First cut at fader schema, new libraries and consistent power naming
    [board-controller.kicad_pcb, board-controller.sch, board-master.kicad_pcb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]
2018-01-27 Added gitignore for KiCAD
2018-01-27 Adding L293 lib, moving motor to sensible place in fader lib
    [board-x8-fader-display.sch]
2018-01-27 Fader board schematic updates
    [board-x8-fader-display.sch]
2018-01-28 adding more wires to schematic, still need board connectors
    [board-x8-fader-display.sch]
2018-01-28 Adding board connection summary
2018-01-28 Added board connections (first pass)
    See https://goo.gl/jBwiur for source (use sheets to markdown add-on)
2018-01-28 Added connector layout
2018-01-28 Completed faders and OLED, some bugs with power pins
    [board-x8-fader-display.sch]
2018-01-28 Fixing schema issues
    [board-x8-fader-display.sch]
2018-01-28 Replaced MPR121 with CAP1296 due to 3.3v limitation - added multiplexed I2C for CAP1296
    [board-x8-fader-display.sch]
2018-01-28 Adding board schematic first revision
2018-01-28 Minor update with note to check I2C pullups
    [board-x8-fader-display.sch]
2018-02-16 Adding Fader data sheet, Schema v1 for faders complete, starting to get footprints sorted out
    [board-x8-fader-display.sch]
2018-02-18 Added LCD footprint and supporting doc
2018-05-17 Updated component maps ready for board layout, adding Thumbs.db to .gitignore
    [board-x8-fader-display.sch]
2018-05-17 Updated first cut at board layout
    [board-x8-fader-display.kicad_pcb, board-x8-fader-display.sch]
2018-05-17 Updated to fix missing power pins for LCDs, updated DFN chips with right pinout
    [board-x8-fader-display.kicad_pcb, board-x8-fader-display.sch]
2018-05-17 Adding DIP library for DIP to DFN converter, Updated board layout with autorouting, hopefully v0.1 final design
    [board-x8-fader-display.kicad_pcb, board-x8-fader-display.sch]
2018-05-17 Added filled version with ground plane (milling?)
    [filled.kicad_pcb]
2018-05-23 Manufacturered board ZIP file
2018-05-28 Motor test now works on all 8 faders)
2018-05-28 Updated for multiple faders (working, OLED won't yet due to board wrong wiring)
    [fader-read.ino, test-oled.ino]
2018-05-28 Snagging complete on Schematic - PCB still out of date
    [board-x8-fader-display.kicad_pcb, board-x8-fader-display.sch, filled.kicad_pcb]
2018-06-02 Updated to add new 74x138 for RST line (to make coding easier)
    [board-x8-fader-display.sch]
2018-06-02 Updated with new DRSTx functionality, Updated silkscreen for fader to include cut slot and screws (for use with panel cutter), Still need to modify display silkscreen, Sanitised .gitignore
    [board-x8-fader-display.kicad_pcb, board-x8-fader-display.sch]
2018-06-03 Updated displays with silkscreen additions for cutouts, Updated PCB latest version (NOTE may need to change CAP1296 DFN to DIP adaptor depending on recent purchase / availability
    [board-x8-fader-display.kicad_pcb]
2018-06-03 Adding skeleton project for Arduino Mega faderboard
    NOTE: This uses https://github.com/ladislas/Bare-Arduino-Project
2018-06-04 Adding silkscreen files
    [board-x8-fader-display-Edge.Cuts.dxf, board-x8-fader-display-F.SilkS.dxf]
2018-06-07 Adding lasercut file for fader board
    [Lasercut.dxf]
2018-06-10 Updating PCB and schema for ProtoAdvantage DIP to DFN adapter (not great but easier than SMD on this board). Rerouting and manual edits to conform to DRC / track & pad clearance
    [board-x8-fader-display.kicad_pcb, board-x8-fader-display.sch]
2018-06-11 Adding boundary to Lasercut
    [Lasercut.dxf]
2018-06-12 Amended library for PROTO DIP adapter to proper hole size, exported final v1.0 board for fabrication, Lasercut now complete with sides and base.
    [Lasercut.dxf, board-x8-fader-display.kicad_pcb]
2018-06-16 Adding arduino kicad library for shield
2018-06-16 Update board connections for v1.0 board
2018-06-16 Removing unused kicad files
    [board-controller.kicad_pcb, board-controller.sch, board-master.kicad_pcb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]
2018-06-16 Adding board controller and RFM library submodule
2018-06-16 Adding libraries for Arduino and RFM, First cut at controller schematic
    [board-controller-2560hat.kicad_pcb, board-controller-2560hat.sch]
2018-06-16 Adding component libraries and docs for keypad and LED drivers. Still need to add TFT before complete
    [board-controller-2560hat.sch]
2018-06-17 Adding retry code to avoid continual radio pounding
    [faderboard-mega.ino]
2018-06-17 Updated to add TFT display components, and now using customer SSD1331 module to fix mixed mode problem
    [faderboard-mega.ino]
2018-06-17 Fixing TFT_ pinouts and rebuilding PCB
    [board-controller-2560hat.kicad_pcb, board-controller-2560hat.sch]
2018-06-17 Adding first autoroute - still need to check nets are correct
    [board-controller-2560hat.kicad_pcb]
2018-06-21 Completed v0.1 of controller board, added PDFs for boards and datasheet for RFM radio
    [board-controller-2560hat.kicad_pcb]
2018-06-23 Tidying board output file locations, corrected silkscreen for v1.0 fader board (not fabbed)
    [Fader Lasercut.dxf, board-x8-fader-display-Edge.Cuts.dxf, board-x8-fader-display-F.SilkS.dxf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]
2018-06-23 Adding Inkscape doc and tidying DXF view
    [Fader Lasercut.dxf]
2018-07-15 Added new T-Slot version of the box
    [Fader T-Slot Box.dxf]
2018-10-06 Changes to BAUD for tests, major update for faderboard code to work with current PCB versions (incl BSEL screw-up)
